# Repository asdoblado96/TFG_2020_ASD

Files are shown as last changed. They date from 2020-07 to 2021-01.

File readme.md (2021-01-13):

# Open source training FPGA board

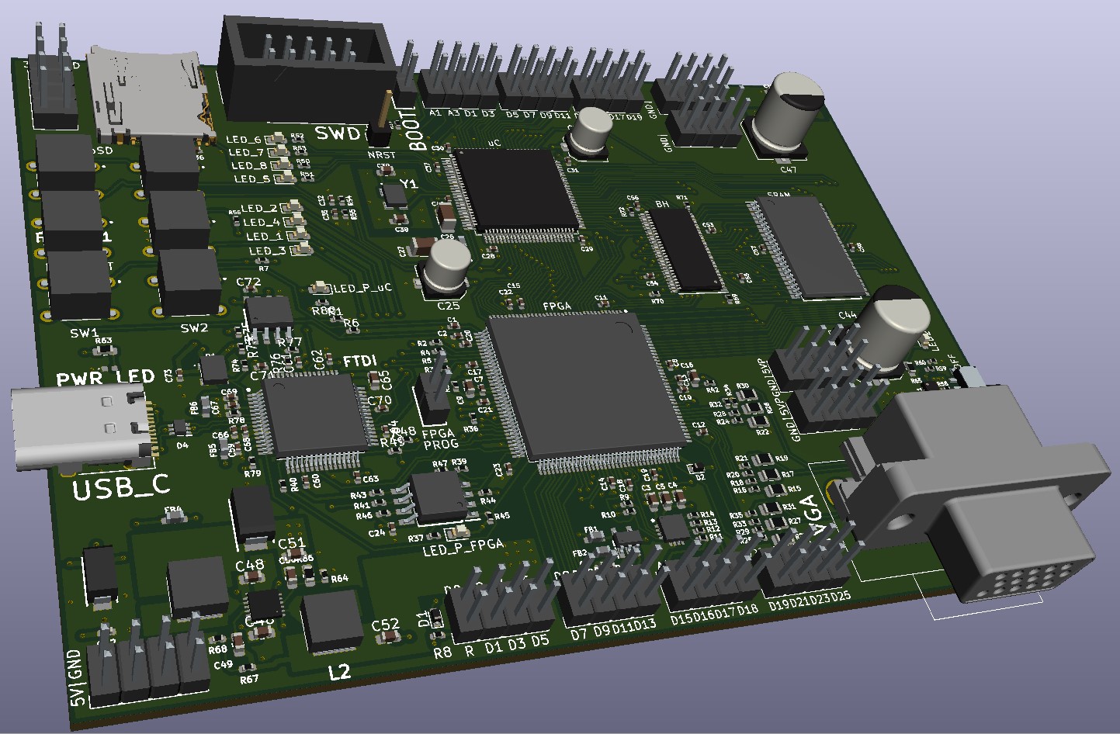
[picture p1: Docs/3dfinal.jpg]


This board was developed as a final bachelor project.

It came up as an opportunity to design an open source board that combines the advantages of both, microcontrollers and FPGAs, devices in one product. As an open source project, you will find all necessary files and information in this repository.

Please, take into account that the board was developped as an student. The purpose of this project was merely to learn about electronics and electronic product development. Please, don't hesitate to contact me in case of doubt, suggestion or if you find any error. 

Thank you.

## Features

* Open hardware
* FPGA:
    * iCE40HX4K (Lattice) FPGA development board (8K using opensource toolchain).
    * 32Mb flash memory for up to 30 bitstreams or FPGA user data.
    * 12 MHZ MEMS oscillator.
    * 4 general purpose LEDs (user LEDs).
    * 2 general purpose pushbuttons.
    * Reset pushbutton and accessible external pin.
    * VGA port.
    * 30 I/O pins (26 digital and 4 analog pins).
    * 4-Channels, 12 bits A/D converter.
    * Compatible with the opensource [Icestudio](https://github.com/FPGAwars/icestudio/).
    * Programmable by USB.
* Microcontroller:
    * STM32F091VC microcontroller.
    * 256Kbyte flash memory and 32Kbyte RAM memory.
    * Internal 8MHZ clock and external 32MHZ crystal oscillator clock.
    * 4 general purpose LEDs (user LEDs).
    * 2 general purpose pushbuttons.
    * Reset pushbutton and accessible external pin.
    * MicroSD card reader.
    * SWD connector for using ST-Link V2.
    * 24 I/O pins (20 digital and 4 analog pins).
    * 1 SPI, 1 I2C and 6 UART compatible pins.
    * Programmable by USB or by St-Link.
* General:
    * FTDI chip allows programming both devices (previously selected by an external jumper). 
    * 4MB shared SRAM between microcontroller and FPGA (to be used as storage or as a communication buffer between devices).
    * USB C power supply (up to 5A).
    * 24 accessible power pins (5V and 3.3V) and 24 GND pins.

## Author

* [Alejandro Sánchez Doblado](https://www.linkedin.com/in/alejandro-s%C3%A1nchez-doblado-014724183/)

## Credits

* This project was derived from the [Icezum Alhambra V2 board](https://github.com/FPGAwars/Alhambra-II-FPGA)

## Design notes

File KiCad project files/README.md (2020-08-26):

# TFG_2020_ASD
KiCad files of the project

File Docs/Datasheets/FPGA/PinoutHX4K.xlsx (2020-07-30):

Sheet: Pinout
iCE40 Pinout HX4K
Pin Function | Pin Type | Bank | (BG121) 121-Ball caBGA Ball Number | (CB132) 132-Ball csBGA Ball Number | (TQ144) 144-Pin TQFP Pin Number
IOL_2A | DPIO | 3 | B1 | B1 | 1 | D1
IOL_2B | DPIO | 3 | B2 | C1 | 2 | D0
IOL_3A | DPIO | 3 | - | - | 3 | D3
IOL_3B | DPIO | 3 | - | - | 4 | D2
GND | GND | GND | - | A9 | 5
VCCIO_3 | VCCIO | VCCIO | - | E3 | 6
IOL_4A | DPIO | 3 | C4 | C3 | 7 | D5
IOL_4B | DPIO | 3 | C3 | D3 | 8 | D4
IOL_5A | DPIO | 3 | C2 | D1 | 9 | D7
IOL_5B | DPIO | 3 | C1 | E1 | 10 | D6
IOL_8A | DPIO | 3 | E1 | D4 | 11
IOL_8B | DPIO | 3 | D1 | E4 | 12
IOL_9A | DPIO | 3 | D2 | F4 | -
IOL_9B | DPIO | 3 | D3 | F3 | -
GND | GND | GND | - | F1 | 13
GND | GND | GND | - | F7 | 14
IOL_10A | DPIO | 3 | E2 | H4 | 15
IOL_10B | DPIO | 3 | E3 | G4 | 16
IOL_12A | DPIO | 3 | F1 | J3 | 17
IOL_12B | DPIO | 3 | F2 | J1 | 18
IOL_13A | DPIO | 3 | F4 | G3 | 19 | D9
IOL_13B_GBIN7 | GBIN | 3 | F3 | G1 | 20 | D8
IOL_14A_GBIN6 | GBIN | 3 | G1 | H1 | 21 | D11
IOL_14B | DPIO | 3 | G2 | H3 | 22 | D10
IOL_17A | DPIO | 3 | G3 | - | 23
IOL_17B | DPIO | 3 | H3 | - | 24
IOL_18A | DPIO | 3 | H1 | K3 | 25
IOL_18B | DPIO | 3 | H2 | K4 | 26
VCC | VCC | VCC | - | F8 | 27
IOL_23A | DPIO | 3 | J1 | L1 | 28
IOL_23B | DPIO | 3 | K1 | M1 | 29
VCCIO_3 | VCCIO | VCCIO | E4 | J6 | 30
IOL_24A | DPIO | 3 | - | - | 31
IOL_24B | DPIO | 3 | - | - | 32
IOL_25A | DPIO | 3 | K2 | N1 | 33 | U_SW2
IOL_25B | DPIO | 3 | J2 | P1 | 34 | U_SW1
IOB_56 | PIO | 2 | L1 | P2 | 37
IOB_57 | PIO | 2 | J3 | - | 38
IOB_59 | PIO | 2 | - | P3 | -
IOB_61 | PIO | 2 | L2 | - | 39
VCC | VCC | VCC | D8 | G6 | 40
IOB_63 | PIO | 2 | K3 | M4 | 41
IOB_64 | PIO | 2 | J4 | M3 | 42 | LED3
IOB_71 | PIO | 2 | L3 | L5 | 43 | LED2
IOB_72 | PIO | 2 | L4 | L4 | 44 | LED1
IOB_73 | PIO | 2 | K4 | P4 | 45 | LED0
IOB_74 | PIO | 2 | - | P5 | -
IOB_77 | PIO | 2 | - | M6 | -
IOB_78 | PIO | 2 | J5 | L6 | -
VCCIO_2 | VCCIO | VCCIO | H6 | J9 | 46
IOB_79 | PIO | 2 | K5 | M7 | 47
IOB_80 | PIO | 2 | - | - | 48
IOB_81_GBIN5 | GBIN | 2 | L5 | P7 | 49 | ICE_CLK
IOB_82_GBIN4 | GBIN | 2 | K6 | P8 | 52
GNDPLL0 | GNDPLL | GNDPLL | L6 | L7 | 53
VCCPLL0 | VCCPLL | VCCPLL | J6 | M8 | 54
IOB_87 | PIO | 2 | H7 | L8 | -
IOB_89 | PIO | 2 | K7 | P9 | -
IOB_91 | PIO | 2 | J8 | M9 | 55
IOB_94 | PIO | 2 | L7 | - | 56
VCCIO_2 | VCCIO | VCCIO | - | M5 | 57
GND | GND | GND | E5 | G7 | 59
IOB_95 | PIO | 2 | - | - | 60
IOB_96 | PIO | 2 | - | - | 61
IOB_102 | PIO | 2 | - | - | 62
IOB_103_CBSEL0 | PIO | 2 | L8 | L9 | 63 | D12
IOB_104_CBSEL1 | PIO | 2 | H9 | P10 | 64 | D13
CDONE | CONFIG | 2 | K8 | M10 | 65
CRESET_B | CONFIG | 2 | L9 | L10 | 66
IOB_105_SDO | SPI | SPI | K9 | M11 | 67
IOB_106_SDI | SPI | SPI | J9 | P11 | 68
GND | GND | GND | E6 | G8 | 69
IOB_107_SCK | SPI | SPI | L10 | P12 | 70
IOB_108_SS | SPI | SPI | K10 | P13 | 71
VCC_SPI | SPI | SPI | L11 | L11 | 72
IOR_109 | PIO | 1 | - | M12 | 73
IOR_110 | PIO | 1 | - | P14 | 74
IOR_111 | PIO | 1 | - | L12 | 75
IOR_112 | PIO | 1 | - | N14 | 76
NC | NC | NC | - | M14 | 77
IOR_114 | PIO | 1 | J11 | L14 | 78
IOR_115 | PIO | 1 | K11 | K12 | 79
IOR_116 | PIO | 1 | H10 | K11 | 80
IOR_117 | PIO | 1 | J10 | K14 | 81
IOR_118 | PIO | 1 | G8 | J12 | 82
IOR_119 | PIO | 1 | H11 | J11 | 83 | ADC_SDA
IOR_120 | PIO | 1 | G10 | H12 | 84 | ADC_SCL
IOR_128 | PIO | 1 | G9 | H11 | 85
IOR_129 | PIO | 1 | G11 | G12 | -
GND | GND | GND | E7 | G9 | 86
IOR_136 | PIO | 1 | F10 | G11 | 87
IOR_137 | PIO | 1 | F9 | F12 | 88
VCCIO_1 | VCCIO | VCCIO | - | F9 | 89
IOR_138 | PIO | 1 | - | - | 90 | ADC_INT
IOR_139 | PIO | 1 | - | - | 91
VCC | VCC | VCC | D4 | H9 | 92
IOR_140_GBIN3 | GBIN | 1 | F11 | F14 | 93
IOR_141_GBIN2 | GBIN | 1 | E10 | G14 | 94
IOR_144 | PIO | 1 | E9 | F11 | 95
IOR_146 | PIO | 1 | E8 | E11 | 96
IOR_147 | PIO | 1 | D9 | E12 | 97
IOR_148 | PIO | 1 | E11 | E14 | 98
IOR_152 | PIO | 1 | D11 | D14 | 99
IOR_154 | PIO | 1 | D10 | C14 | -
VCCIO_1 | VCCIO | VCCIO | F8 | H14 | 100
IOR_160 | PIO | 1 | C11 | D12 | 101
IOR_161 | PIO | 1 | B11 | B14 | 102
GND | GND | GND | F5 | H6 | 103
IOR_164 | PIO | 1 | - | - | 104
IOR_165 | PIO | 1 | - | - | 105
IOR_166 | PIO | 1 | - | - | 106
IOR_167 | PIO | 1 | - | - | 107
VPP_2V5 | VPP | VPP | C10 | A14 | 108
VPP_FAST | VPP | VPP | B10 | A13 | 109
IOT_168 | PIO | 0 | A11 | - | 110
VCC | VCC | VCC | - | J4 | 111
IOT_169 | PIO | 0 | - | - | 112
IOT_170 | PIO | 0 | A10 | A12 | 113
IOT_171 | PIO | 0 | - | - | 114 | A0
IOT_172 | PIO | 0 | C9 | C12 | 115 | A1
IOT_173 | PIO | 0 | - | - | 116 | A2
IOT_174 | PIO | 0 | B9 | C11 | 117 | A3
IOT_177 | PIO | 0 | B8 | D10 | 118
IOT_178 | PIO | 0 | A9 | D11 | 119
IOT_179 | PIO | 0 | C8 | A11 | 120
IOT_181 | PIO | 0 | D7 | A10 | 121
IOT_186 | PIO | 0 | - | C10 | -
IOT_188 | PIO | 0 | - | D9 | -
IOT_190 | PIO | 0 | A8 | C9 | 122
VCCIO_0 | VCCIO | VCCIO | - | A8 | 123
IOT_191 | PIO | 0 | C7 | - | 124
IOT_192 | PIO | 0 | A7 | - | 125
VCCPLL1 | VCCPLL | VCCPLL | C6 | C8 | 126
GNDPLL1 | GNDPLL | GNDPLL | C5 | D8 | 127
IOT_197_GBIN1 | GBIN | 0 | B7 | A7 | 128
IOT_198_GBIN0 | GBIN | 0 | B6 | A6 | 129
IOT_200 | PIO | 0 | - | C7 | -
IOT_202 | PIO | 0 | - | D7 | -
IOT_206 | PIO | 0 | A6 | C6 | 130
IOT_207 | PIO | 0 | A5 | D6 | -
IOT_208 | PIO | 0 | B5 | A5 | -
IOT_211 | PIO | 0 | A4 | D5 | -
VCCIO_0 | VCCIO | VCCIO | - | F6 | 131
GND | GND | GND | F6 | H7 | 132
IOT_212 | PIO | 0 | D5 | C5 | 134
IOT_213 | PIO | 0 | - | - | 135
IOT_214 | PIO | 0 | - | - | 136
IOT_215 | PIO | 0 | - | - | 137
IOT_216 | PIO | 0 | - | - | 138
IOT_217 | PIO | 0 | - | - | 139
GND | GND | GND | F7 | H8 | 140
IOT_219 | PIO | 0 | B4 | A4 | 141
IOT_220 | PIO | 0 | - | - | 142
IOT_221 | PIO | 0 | B3 | C4 | 143
IOT_222 | PIO | 0 | A2 | A3 | 144
IOT_223 | PIO | 0 | A3 | A2 | -
IOT_225 | PIO | 0 | A1 | A1 | -
VCC | VCC | VCC | H8 | J7 | -
NC | NC | NC |  | - | 35
NC | NC | NC |  | - | 36
NC | NC | NC |  | - | 50
NC | NC | NC |  | - | 51
NC | NC | NC |  | - | 58
NC | NC | NC |  | - | 133
GND | GND | GND | G5 | J14 | -
GND | GND | GND | G6 | J8 | -
GND | GND | GND | G7 | L3 | -
GND | GND | GND | - | P6 | -
VCCIO_3 | VCCIO | VCCIO | G4 | K1 | -

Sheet: Revision History
Version | Date | Description
3.0 | 2017/05/5 | add "BG121" for "121-Ball caBGA"(new 9x9 mm package ucBGA121), Revision "iCE40HX08.pkt 1.1"
2.1 | 2013-06-13 | Included package ordering code.
2.0 | 2013-03-13 | Updated table format to include all packages
1.0 | 10/1/2012 | Chnaged name from "TQ144" to "144-pin TQFP" Production Release
0.92 | 2011-12-14 | Package drawing, removed option notes 6 and 7
0.91 | 2011-11-13 | 1K pins 40, 49, 50, 52, 133, 134 updated
0.9 | 2011-10-31 | Preliminary

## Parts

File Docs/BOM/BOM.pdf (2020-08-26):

Referencia | Valor | Huella | CantidadPrecio
> C1, C2, C7, C8, C10-C15, C17-C24, C28-C32, C35-C37, C40, C42, C53-C64, C66-C73 C100n | Capacitor_SMD:C_0402_1005Metric | 48 | 3.456
> C5, C9, C16, C34, C46, C48, C51, C52, C65 C10u | Capacitor_SMD:C_0603_1608Metric | 9 | 2.088
> C3, C4, C6, C41, C43, C45 | C100n | Capacitor_SMD:C_0603_1608Metric | 6 | 0.306
> C25, C33 | C4.7uElect | Capacitor_SMD:C_Elec_5x5.4 | 2 | 0.528
C26 | C1u | Capacitor_SMD:C_1206_3216Metric | 1 | 0.263
C27 | C10n | Capacitor_SMD:C_1206_3216Metric | 1 | 0.082
> C38, C39 | C20p | Capacitor_SMD:C_0603_1608Metric | 2 | 0.229
> C44, C47 | C220uElect | Capacitor_SMD:CP_Elec_8x10 | 2 | 0.638
> C49, C50 | 100p | Capacitor_SMD:C_0603_1608Metric | 2 | 0.148
> D1, D2 | D_Schottky | Diode_SMD:D_SOD-523 | 2 | 0.078
D3 | 824500500 | TFG_20:DIOM5127X250N | 1 | 0.225
D4 | 82400152 | TFG_20:SOTFL50P160X60-6N | 1 | 0.48
> FB1-FB6 | BLM18KG331SN1D | TFG_20:BEADC1608X95N | 6 | 0.228
IC1 | ADS7924IRTER | TFG_20:QFN50P300X300X80-17N-D | 1 | 1.6
IC2 | NCP114BSN330T1G | TFG_20:SOT95P275X110-5N | 1 | 0.2
IC3 | iCE40HX4K-TQ144 | TFG_20:QFP50P2200X2200X160-144N | 1 | 5.34
IC4 | W25Q32JVSSIQ | TFG_20:SOIC127P790X216-8N | 1 | 0.584
IC5 | NCP708MU330TAG | TFG_20:SON95P300X300X55-7N | 1 | 0.39
IC6 | IS61WV25616EDBLL-10TLI | TFG_20:SOP80P1176X120-44N | 1 | 2.33
IC7 | 93LC56C-I_SN | TFG_20:SOIC127P600X175-8N | 1 | 0.203
> J1-J4, J6, J7, J9, J13-J20 | 10129381-908002BLF | HDRV8W67P254_2X4_1016X483X858P | 7 | 4.2
J5 | L77HDE15SD1CH4RHNVGA | TFG_20:L77HDE15SD1CH4RHNVGA | 1 | 1.38
J8 | 1761681-3 | SHDR10W67P254_2X5_2032X916X922P | 1 | 1.26
J10 | Conn_01x01 | Connector_PinHeader_2.54mm:PinHeader_1x01_P2.54mm_Vertical 1 | 0.085
J11 | Micro_SD_Card | Connector_Card:microSD_HC_Molex_104031-08111 | 2.92
J12 | USB_C_Receptacle_USB2.0 | Connector_USB:USB_C_Receptacle_Amphenol_12401610E4-2A 1 | 1.6
> L1, L2 | LQH5BPN4R7NT0L | TFG_20:LQH5BPB100MT0L | 2 | 0.42
> LED1, LED_1, LED_8, LED_FP1 | LED_AMARILLO | LED_SMD:LED_0603_1608Metric | 4 | 0.4
> LED2, LED_2, LED_7, PWR_LED1 LED_AZUL | LED_SMD:LED_0603_1608Metric | 4 | 0.474
> LED_3, LED_6 | LED_VERDE | LED_SMD:LED_0603_1608Metric | 2 | 0.332
> LED_4, LED_5 | LED_ROJO | LED_SMD:LED_0603_1608Metric | 2 | 0.292
O1 | DSC1001CL2 | TFG_20:DSC1001CI50081920 | 1 | 0.805

Q1 | DMP1005UFDF-7 | TFG_20:DFN-6-2EP-2.05-2.05 | 1 | 0.362
> R1, R6, R8-R10, R36, R44-R48, R54, R55, R57, R59, R60, R66-R73, R75, R76, R78 R10k | Resistor_SMD:R_0402_1005Metric | 27 | 1.215
> R2-R5, R39-R41, R43, R50-R53 | R470 | Resistor_SMD:R_0402_1005Metric | 12 | 0.4548
> R7, R49, R56, R61, R62, R79 | R1K | Resistor_SMD:R_0402_1005Metric | 6 | 0.176
> R11-R14, R21, R34, R35, R38, R42, R58, R74, R80 R100 | Resistor_SMD:R_0402_1005Metric | 12 | 1.68
> R15, R17, R19, R22, R23, R26, R27, R30, R31 R309 | Resistor_SMD:R_0805_2012Metric | 9 | 0.9
> R16, R18, R20, R24, R25, R28, R29, R32, R33 R619 | Resistor_SMD:R_0402_1005Metric | 9 | 0.216
> R37,R63, R65, R77 | R2k2 | Resistor_SMD:R_0402_1005Metric | 4 | 0.04
R64 | 45k | Resistor_SMD:R_0603_1608Metric | 1 | 0.79
S1 | PCM12SMTR | TFG_20:PCM12SMTR_1 | 1 | 0.8
U1 | STM32F091VCTx | Package_QFP:LQFP-100_14x14mm_P0.5mm | 1 | 4.26
U2 | PAM2306AYPKB | Package_DFN_QFN:WDFN-12-1EP_3x3mm_P0.45mm_EP1.7x2.5mm 1 | 0.344
U3 | SN74ALVCH162827 | Package_SO:TSSOP-56_6.1x14mm_P0.5mm | 1 | 1.56
U4 | FT2232H | TFG_20:QFP50P1200X1200X160-64N | 1 | 4.19
> FPGA_R1, uC_R1, USW1-USW4 | FSM2JLH | FSM2JLH | 6 | 0.6
Y1 | ECS-320-12-33B-7KM-TR | ECS3201233B7KMTR | 1 | 0.33
Z1 | 3.3V | TFG_20:DIOM5436X247N | 1 | 0.12
| | | | 51.602

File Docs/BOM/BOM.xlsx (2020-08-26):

Referencia | Valor | Huella | Datasheet | Cantidad | Precio
> C1, C2, C7, C8, C10-C15, C17-C24, C28-C32, C35-C37, C40, C42, C53-C64, C66-C73 | C100n | Capacitor_SMD:C_0402_1005Metric | https://es.rs-online.com/web/p/mlccs-condensadores-ceramicos-multicapa/9155613/ | 48 | 3.456
> C5, C9, C16, C34, C46, C48, C51, C52, C65 | C10u | Capacitor_SMD:C_0603_1608Metric | https://es.rs-online.com/web/p/mlccs-condensadores-ceramicos-multicapa/7882893/ | 9 | 2.088
> C3, C4, C6, C41, C43, C45 | C100n | Capacitor_SMD:C_0603_1608Metric | https://es.rs-online.com/web/p/mlccs-condensadores-ceramicos-multicapa/2644630/ | 6 | 0.306
> C25, C33 | C4.7uElect | Capacitor_SMD:C_Elec_5x5.4 | https://es.rs-online.com/web/p/condensadores-de-aluminio/5369916/ | 2 | 0.528
C26 | C1u | Capacitor_SMD:C_1206_3216Metric | https://es.rs-online.com/web/p/mlccs-condensadores-ceramicos-multicapa/6911195/ | 1 | 0.263
C27 | C10n | Capacitor_SMD:C_1206_3216Metric | https://es.rs-online.com/web/p/mlccs-condensadores-ceramicos-multicapa/2644141/ | 1 | 0.082
> C38, C39 | C20p | Capacitor_SMD:C_0603_1608Metric | https://es.rs-online.com/web/p/mlccs-condensadores-ceramicos-multicapa/7880355/ | 2 | 0.229
> C44, C47 | C220uElect | Capacitor_SMD:CP_Elec_8x10 | https://es.rs-online.com/web/p/condensadores-de-aluminio/7568092/ | 2 | 0.638
> C49, C50 | 100p | Capacitor_SMD:C_0603_1608Metric | https://es.rs-online.com/web/p/mlccs-condensadores-ceramicos-multicapa/2644523/ | 2 | 0.148
> D1, D2 | D_Schottky | Diode_SMD:D_SOD-523 | https://es.rs-online.com/web/p/diodos-schottky-y-rectificadores/7916321/ | 2 | 0.078
D3 | 824500500 | TFG_20:DIOM5127X250N | https://componentsearchengine.com/Datasheets/1/824500500.pdf | 1 | 0.225
D4 | 82400152 | TFG_20:SOTFL50P160X60-6N | http://uk.rs-online.com/web/p/products/7546203P | 1 | 0.48
> FB1-FB6 | BLM18KG331SN1D | TFG_20:BEADC1608X95N | http://uk.rs-online.com/web/p/products/7926265P | 6 | 0.228
IC1 | ADS7924IRTER | TFG_20:QFN50P300X300X80-17N-D | http://www.ti.com/lit/gpn/ads7924 | 1 | 1.6
IC2 | NCP114BSN330T1G | TFG_20:SOT95P275X110-5N | http://uk.rs-online.com/web/p/products/1263179P | 1 | 0.2
IC3 | iCE40HX4K-TQ144 | TFG_20:QFP50P2200X2200X160-144N | https://componentsearchengine.com/Datasheets/1/iCE40HX4K-TQ144.pdf | 1 | 5.34
IC4 | W25Q32JVSSIQ | TFG_20:SOIC127P790X216-8N | https://www.winbond.com/resource-files/w25q32jv%20spi%20revc%2008302016.pdf | 1 | 0.584
IC5 | NCP708MU330TAG | TFG_20:SON95P300X300X55-7N | https://componentsearchengine.com/Datasheets/1/NCP708MU330TAG.pdf | 1 | 0.39
IC6 | IS61WV25616EDBLL-10TLI | TFG_20:SOP80P1176X120-44N | https://componentsearchengine.com/Datasheets/1/IS61WV25616EDBLL-10TLI.pdf | 1 | 2.33
IC7 | 93LC56C-I_SN | TFG_20:SOIC127P600X175-8N | https://componentsearchengine.com/Datasheets/1/93LC56C-I_SN.pdf | 1 | 0.203
> J1-J4, J6, J7, J9, J13-J20 | 10129381-908002BLF | HDRV8W67P254_2X4_1016X483X858P | https://cdn.amphenol-icc.com/media/wysiwyg/files/drawing/10129381.pdf | 7 | 4.2
J5 | L77HDE15SD1CH4RHNVGA | TFG_20:L77HDE15SD1CH4RHNVGA | https://componentsearchengine.com/Datasheets/1/L77HDE15SD1CH4RHNVGA.pdf | 1 | 1.38
J8 | 1761681-3 | SHDR10W67P254_2X5_2032X916X922P | http://www.te.com/commerce/DocumentDelivery/DDEController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 | 1 | 1.26
J10 | Conn_01x01 | Connector_PinHeader_2.54mm:PinHeader_1x01_P2.54mm_Vertical | ~ | 1 | 0.085
J11 | Micro_SD_Card | Connector_Card:microSD_HC_Molex_104031-0811 | http://katalog.we-online.de/em/datasheet/693072010801.pdf | 1 | 2.92
J12 | USB_C_Receptacle_USB2.0 | Connector_USB:USB_C_Receptacle_Amphenol_12401610E4-2A | https://www.usb.org/sites/default/files/documents/usb_type-c.zip | 1 | 1.6
> L1, L2 | LQH5BPN4R7NT0L | TFG_20:LQH5BPB100MT0L | http://uk.rs-online.com/web/p/products/8712085P | 2 | 0.42
> LED1, LED_1, LED_8, LED_FP1 | LED_AMARILLO | LED_SMD:LED_0603_1608Metric | https://es.rs-online.com/web/p/leds/6546079/ | 4 | 0.4
> LED2, LED_2, LED_7, PWR_LED1 | LED_AZUL | LED_SMD:LED_0603_1608Metric | https://es.rs-online.com/web/p/leds/6973610/ | 4 | 0.474
> LED_3, LED_6 | LED_VERDE | LED_SMD:LED_0603_1608Metric | https://es.rs-online.com/web/p/leds/6973715/ | 2 | 0.332
> LED_4, LED_5 | LED_ROJO | LED_SMD:LED_0603_1608Metric | https://es.rs-online.com/web/p/leds/7166570/ | 2 | 0.292
O1 | DSC1001CL2 | TFG_20:DSC1001CI50081920 | https://www.mouser.es/datasheet/2/268/20005529A-1149183.pdf | 1 | 0.805
Q1 | DMP1005UFDF-7 | TFG_20:DFN-6-2EP-2.05-2.05 | https://es.rs-online.com/web/p/mosfet/1827235/ | 1 | 0.362
> R1, R6, R8-R10, R36, R44-R48, R54, R55, R57, R59, R60, R66-R73, R75, R76, R78 | R10k | Resistor_SMD:R_0402_1005Metric | https://es.rs-online.com/web/p/resistencias-fijas-para-montaje-en-superficie/6784697/ | 27 | 1.215
> R2-R5, R39-R41, R43, R50-R53 | R470 | Resistor_SMD:R_0402_1005Metric | https://es.rs-online.com/web/p/resistencias-fijas-para-montaje-en-superficie/1991341/ | 12 | 0.4548
> R7, R49, R56, R61, R62, R79 | R1K | Resistor_SMD:R_0402_1005Metric | https://es.rs-online.com/web/p/resistencias-fijas-para-montaje-en-superficie/7014924/ | 6 | 0.176
> R11-R14, R21, R34, R35, R38, R42, R58, R74, R80 | R100 | Resistor_SMD:R_0402_1005Metric | https://es.rs-online.com/web/p/resistencias-fijas-para-montaje-en-superficie/8121739/ | 12 | 1.68
> R15, R17, R19, R22, R23, R26, R27, R30, R31 | R309 | Resistor_SMD:R_0805_2012Metric | https://es.rs-online.com/web/p/resistencias-fijas-para-montaje-en-superficie/7085979/ | 9 | 0.9
> R16, R18, R20, R24, R25, R28, R29, R32, R33 | R619 | Resistor_SMD:R_0402_1005Metric | https://es.rs-online.com/web/p/resistencias-fijas-para-montaje-en-superficie/1226449/ | 9 | 0.216
> R37,R63, R65, R77 | R2k2 | Resistor_SMD:R_0402_1005Metric | https://es.rs-online.com/web/p/resistencias-fijas-para-montaje-en-superficie/6789071/ | 4 | 0.04
R64 | 45k | Resistor_SMD:R_0603_1608Metric | https://es.rs-online.com/web/p/resistencias-fijas-para-montaje-en-superficie/8409275/ | 1 | 0.79
S1 | PCM12SMTR | TFG_20:PCM12SMTR_1 | http://uk.rs-online.com/web/p/products/7931721P | 1 | 0.8
U1 | STM32F091VCTx | Package_QFP:LQFP-100_14x14mm_P0.5mm | http://www.st.com/st-web-ui/static/active/en/resource/technical/document/datasheet/DM00115237.pdf | 1 | 4.26
U2 | PAM2306AYPKB | Package_DFN_QFN:WDFN-12-1EP_3x3mm_P0.45mm_EP1.7x2.5mm | https://www.diodes.com/assets/Datasheets/PAM2306.pdf | 1 | 0.344
U3 | SN74ALVCH162827 | Package_SO:TSSOP-56_6.1x14mm_P0.5mm | https://www.mouser.es/ProductDetail/Texas-Instruments/SN74ALVCH162836GR | 1 | 1.56
U4 | FT2232H | TFG_20:QFP50P1200X1200X160-64N | https://www.ftdichip.com/Support/Documents/DataSheets/ICs/DS_FT2232H.pdf | 1 | 4.19
> FPGA_R1, uC_R1, USW1-USW4 | FSM2JLH | FSM2JLH | https://www.te.com/commerce/DocumentDelivery/DDEController?Action=showdoc | 6 | 0.6
Y1 | ECS-320-12-33B-7KM-TR | ECS3201233B7KMTR | https://componentsearchengine.com/Datasheets/1/ECS-320-12-33B-7KM-TR.pdf | 1 | 0.33
Z1 | 3.3V | TFG_20:DIOM5436X247N | http://uk.rs-online.com/web/p/products/5453308P | 1 | 0.12
 |  |  |  |  | 51.6018

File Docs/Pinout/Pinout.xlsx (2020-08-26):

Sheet: uC
Pin | UART | SPI | I2C | Otro
A0 | UART1_TX |  |  | EVENT
A1 | UART1_RX |  |  | EVENT
A2 | UART2_TX | SPI_MISO |  | EVENT
A3 | UART2_RX | SPI_MOSI |  | EVENT
D0 |  |  |  | EVENT
 |  |  |  | TIM1_CH1
D1 |  |  |  | EVENT
 |  |  |  | TIM2_CH1
D2 |  | SPI_SS | I2C_SDA | EVENT
 |  |  |  | TIM2_CH1
D3 |  |  | I2C_SCL | TIM1_CH1
D4 | UART3_RX |  | I2C_SDA | TIM2_CH1N
D5 | UART3_TX |  | I2C_SCL | TIM1_CH1N
D6 |  |  |  | WAKEUP1
 |  |  |  | TIM3_CH2
D7 | UART4_RX |  |  | TIM3_CH1
D8 | UART4_TX |  |  | TIM2_CH2
D9 | USART_CK
D10 | USART_RX
D11 | USART_TX
D12 | USART_RTS | SPI_MOSI
D13 | USART_CTS | SPI_MISO
D14 | UART4_RX
D15 |  | SPI_SCK
D16 |  | SPI_SS
D17 | UART4_TX
D18 | UART5_RX
D19 | UART5_TX

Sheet: FPGA
PIN | Función
D19 | GBIN3
D20 | GBIN2

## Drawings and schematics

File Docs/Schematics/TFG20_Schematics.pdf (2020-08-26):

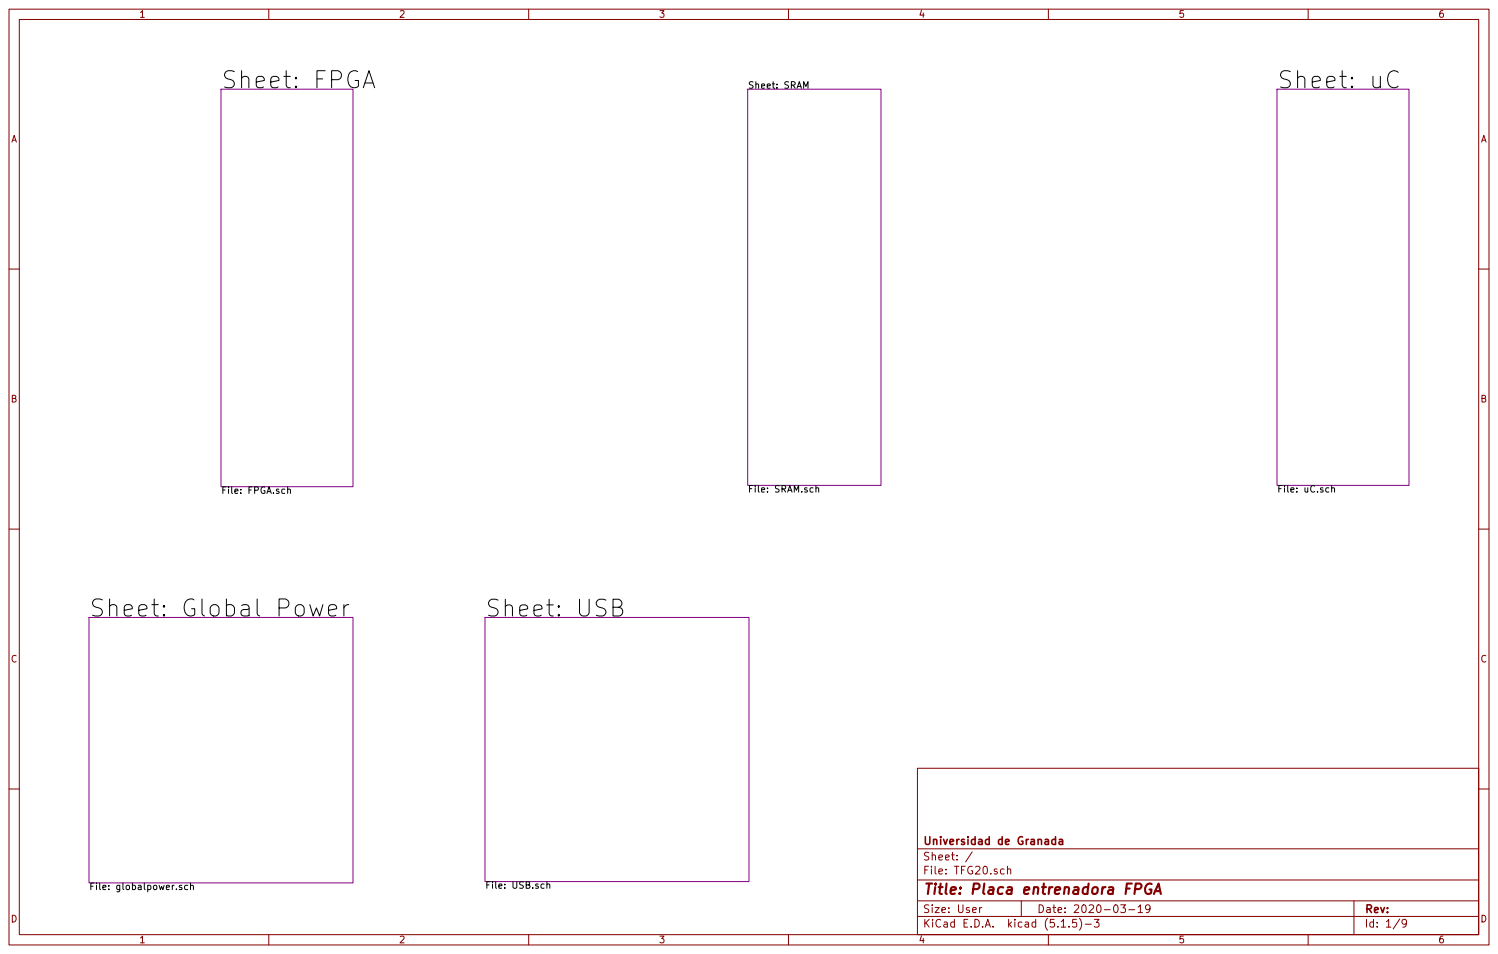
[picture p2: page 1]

Id: 1/9 Title: Placa entrenadora FPGA File: TFG20.sch Sheet: / Universidad de Granada Sheet: FPGA

File: uC.sch Sheet: Global Power

File: SRAM.sch Sheet: USB

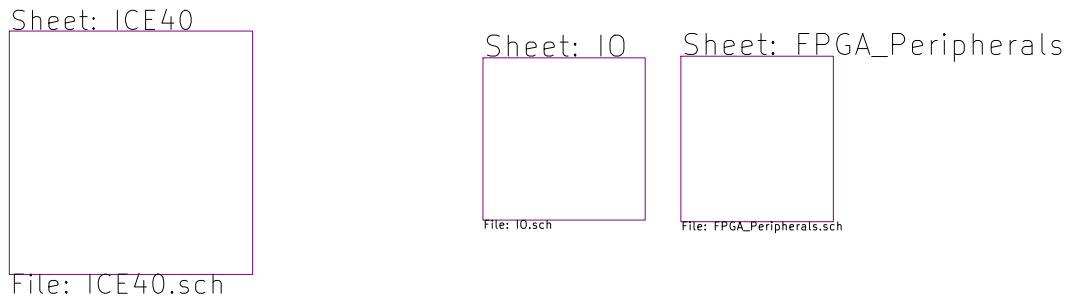
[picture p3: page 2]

Id: 2/9 Title: File: FPGA.sch Sheet: /FPGA/ Sheet: IO

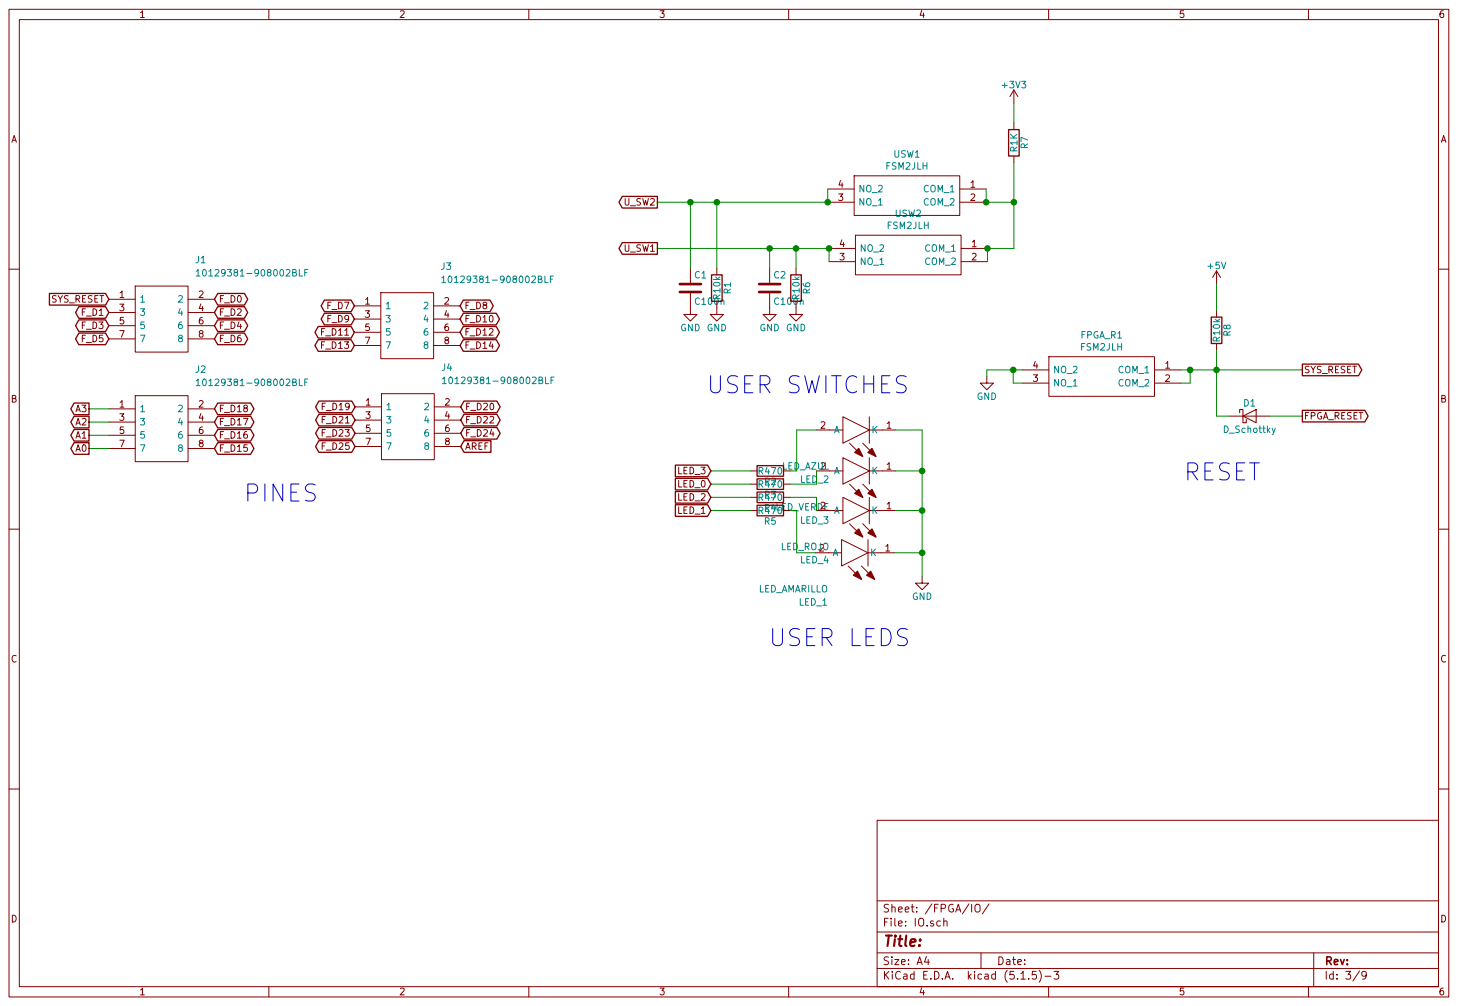
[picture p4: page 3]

Id: 3/9 Title: File: IO.sch Sheet: /FPGA/IO/

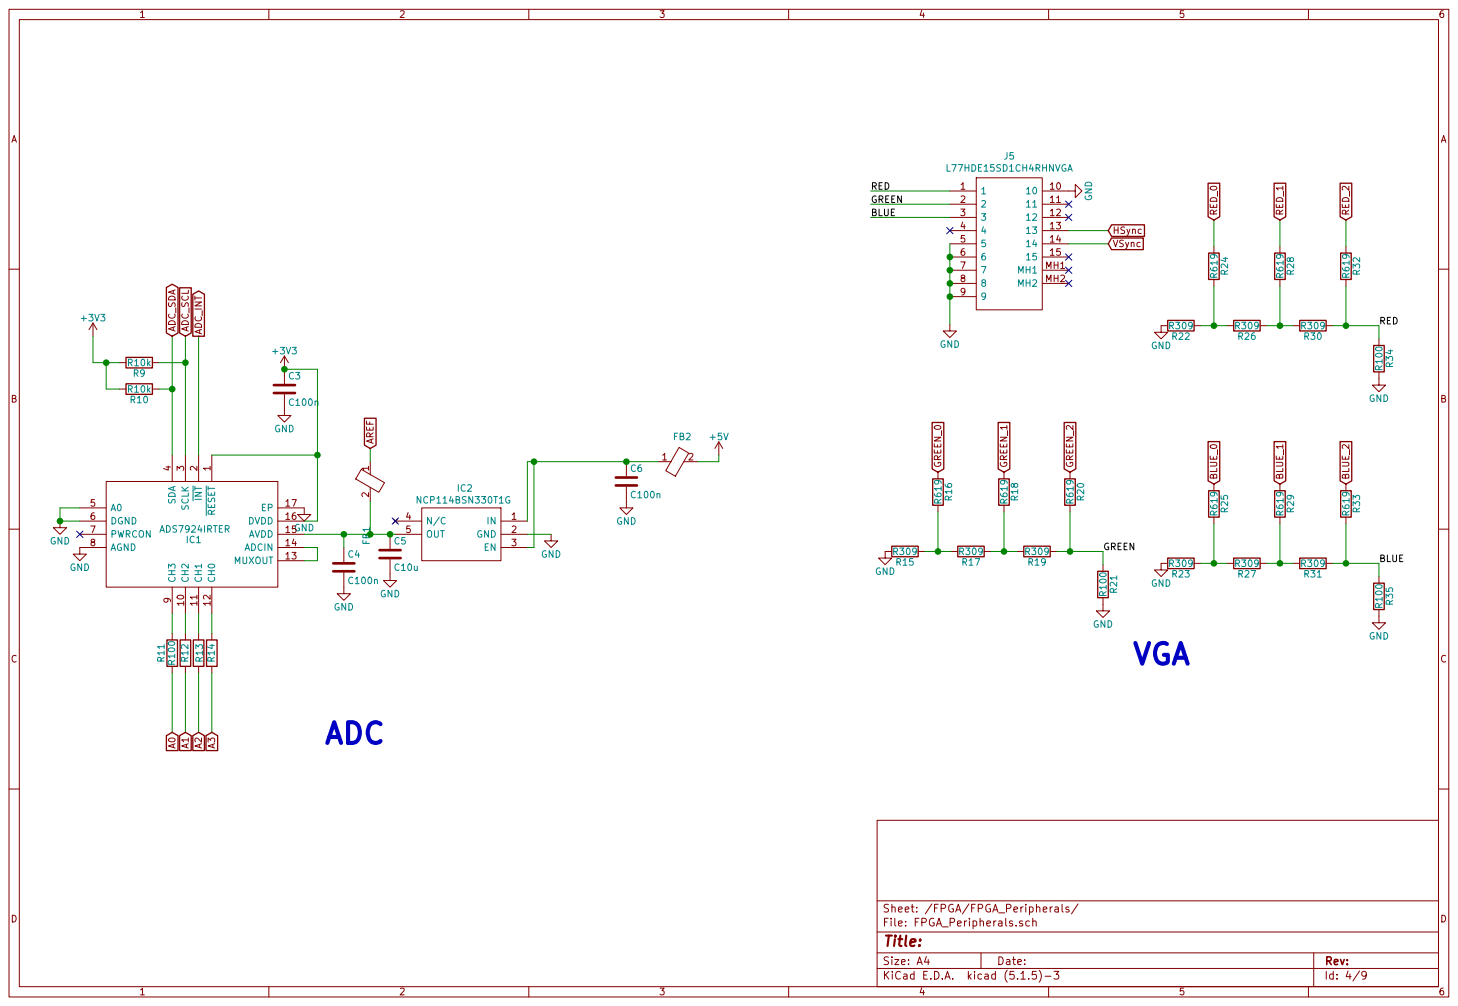
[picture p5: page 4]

1 CH2 10 CH1 11 CH0 12 MUXOUT 13 ADCIN 14 AVDD 15 DVDD 16 EP 17 INT

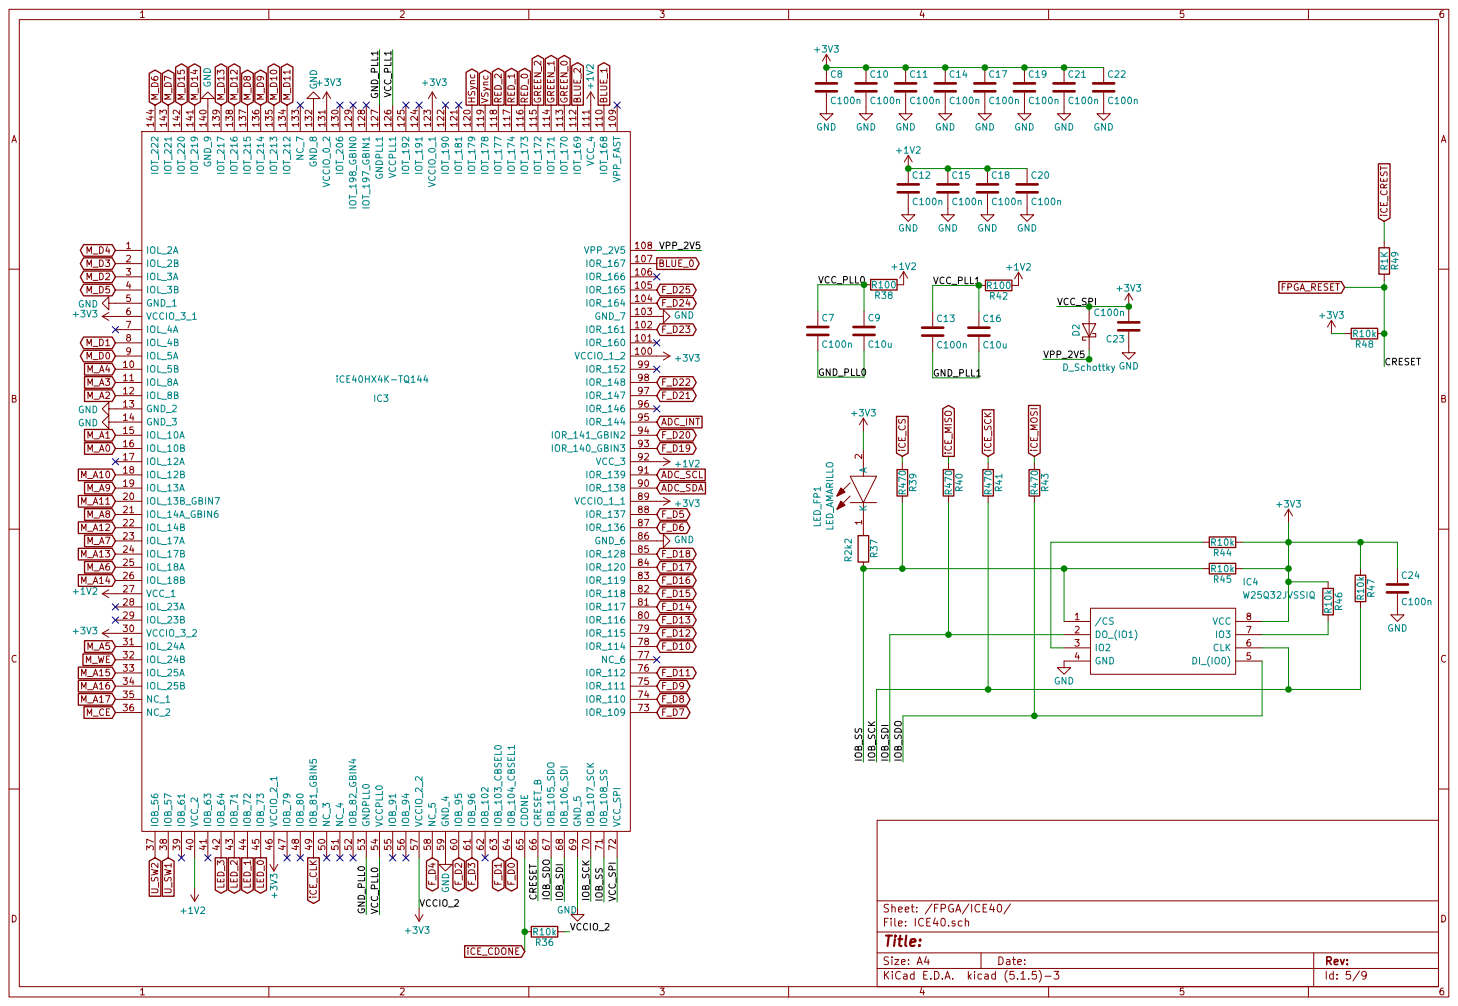
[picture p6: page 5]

Id: 5/9 Title: File: ICE40.sch Sheet: /FPGA/ICE40/ R470 R40 +1V2

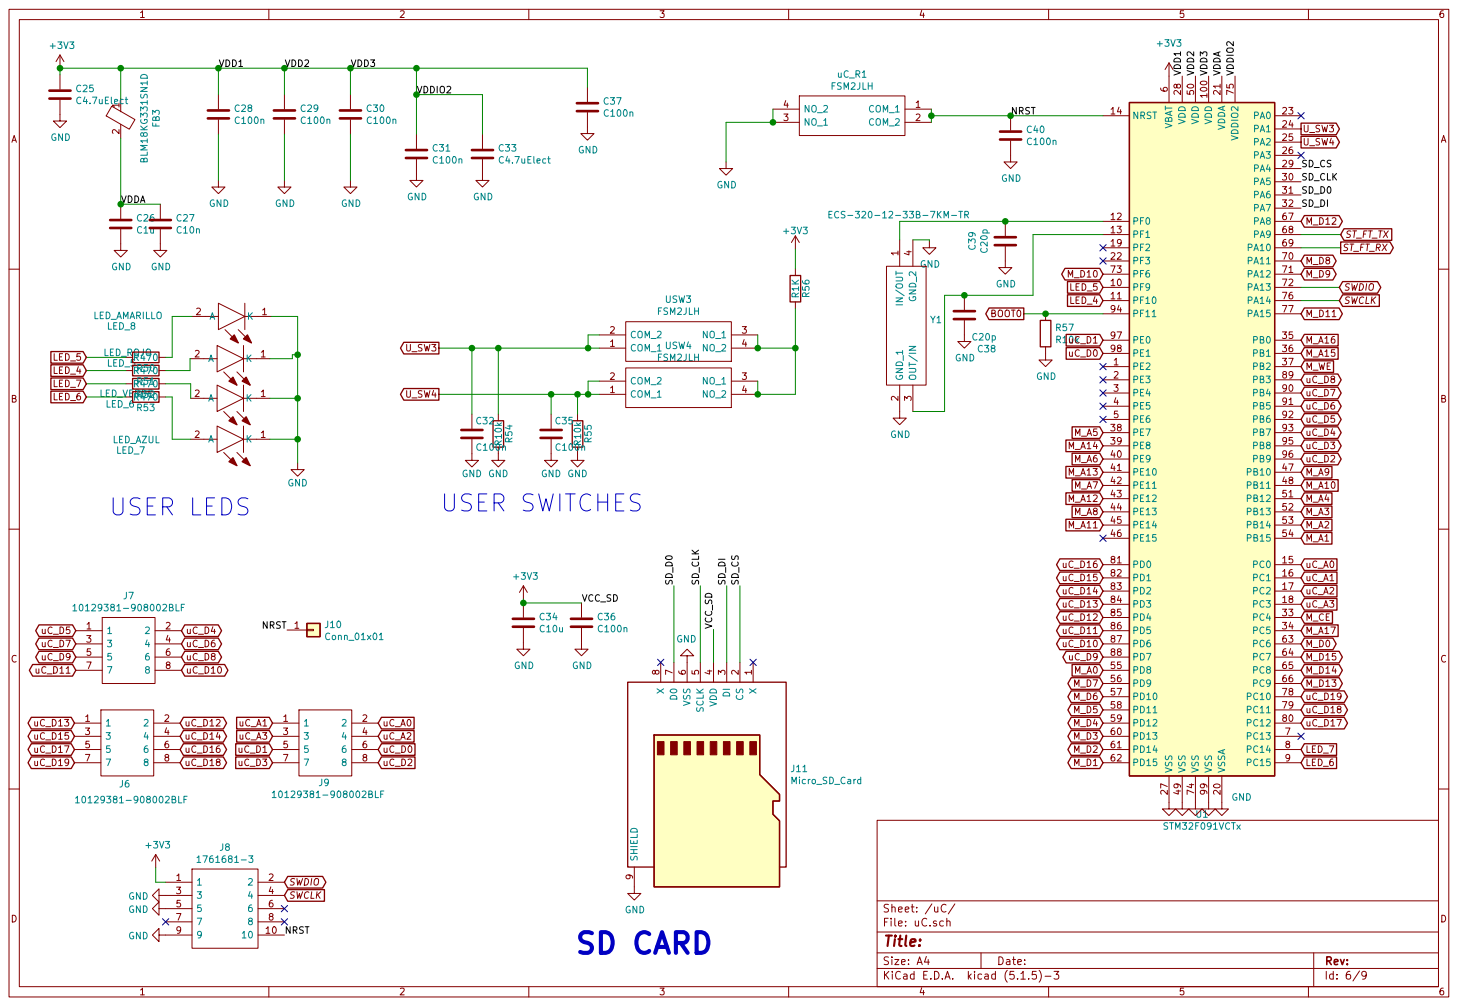
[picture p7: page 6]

Id: 6/9 Title: File: uC.sch Sheet: /uC/

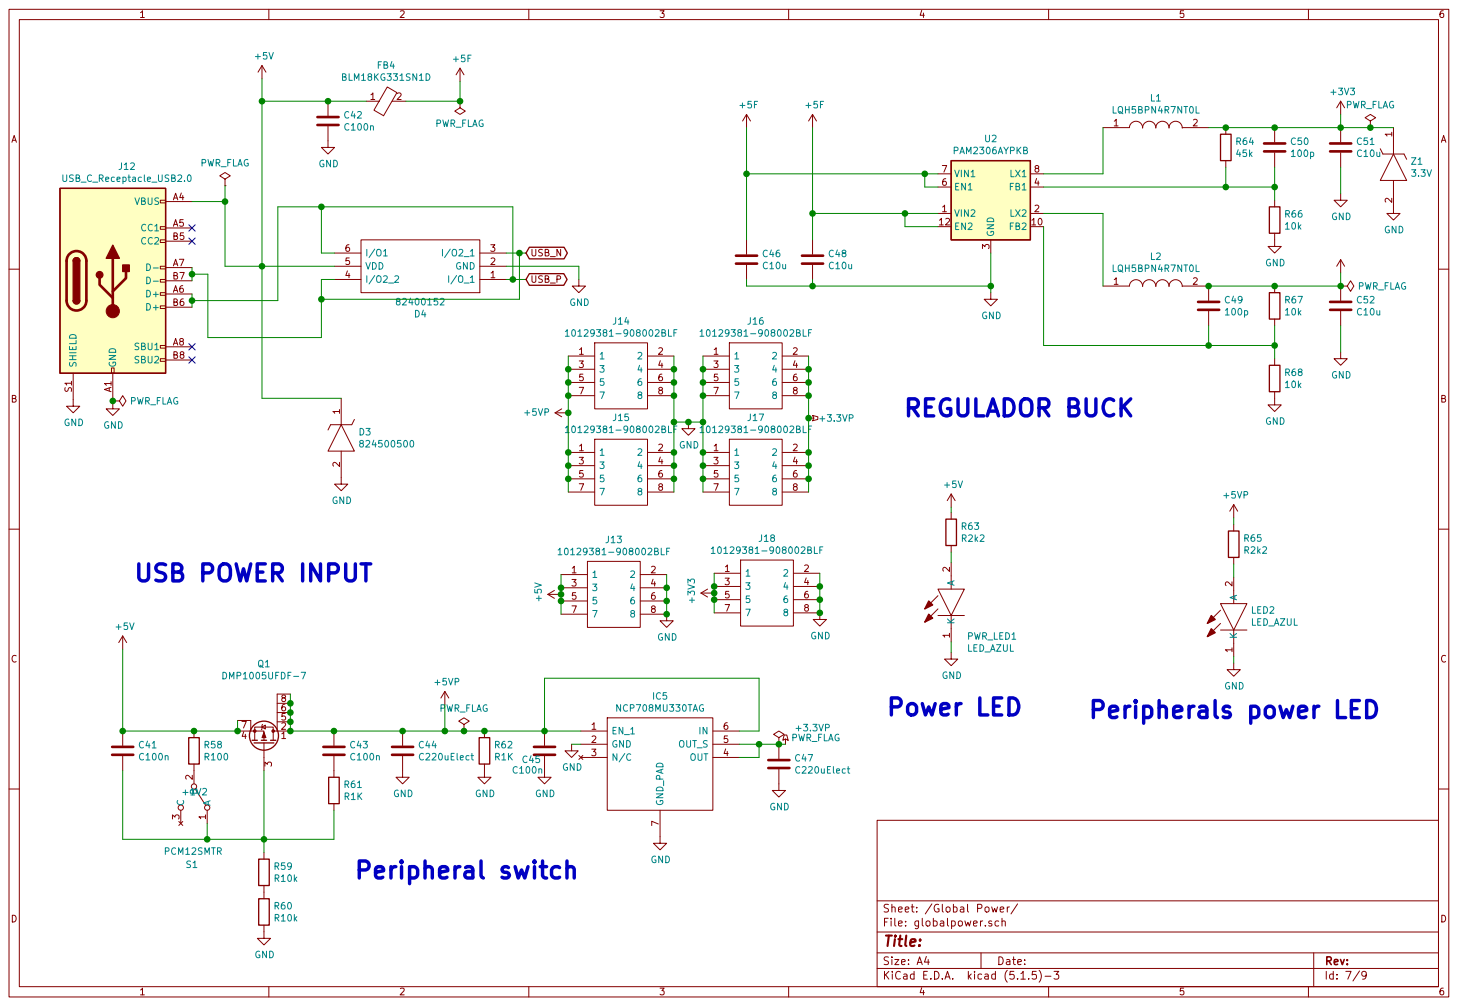
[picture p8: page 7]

File: globalpower.sch Sheet: /Global Power/ C41 C100n

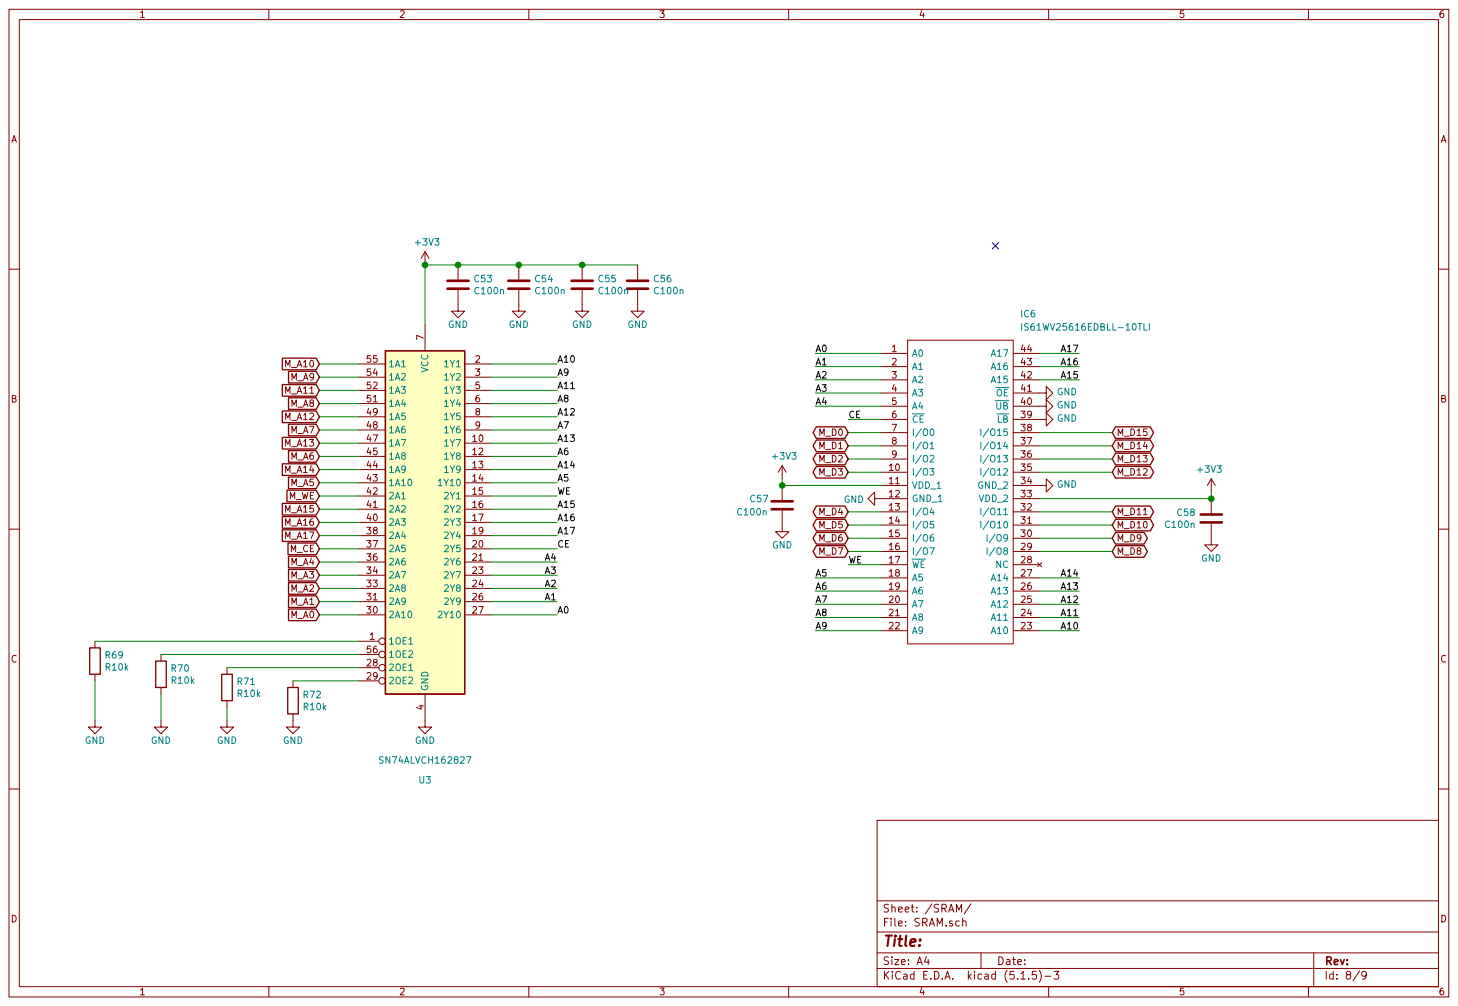
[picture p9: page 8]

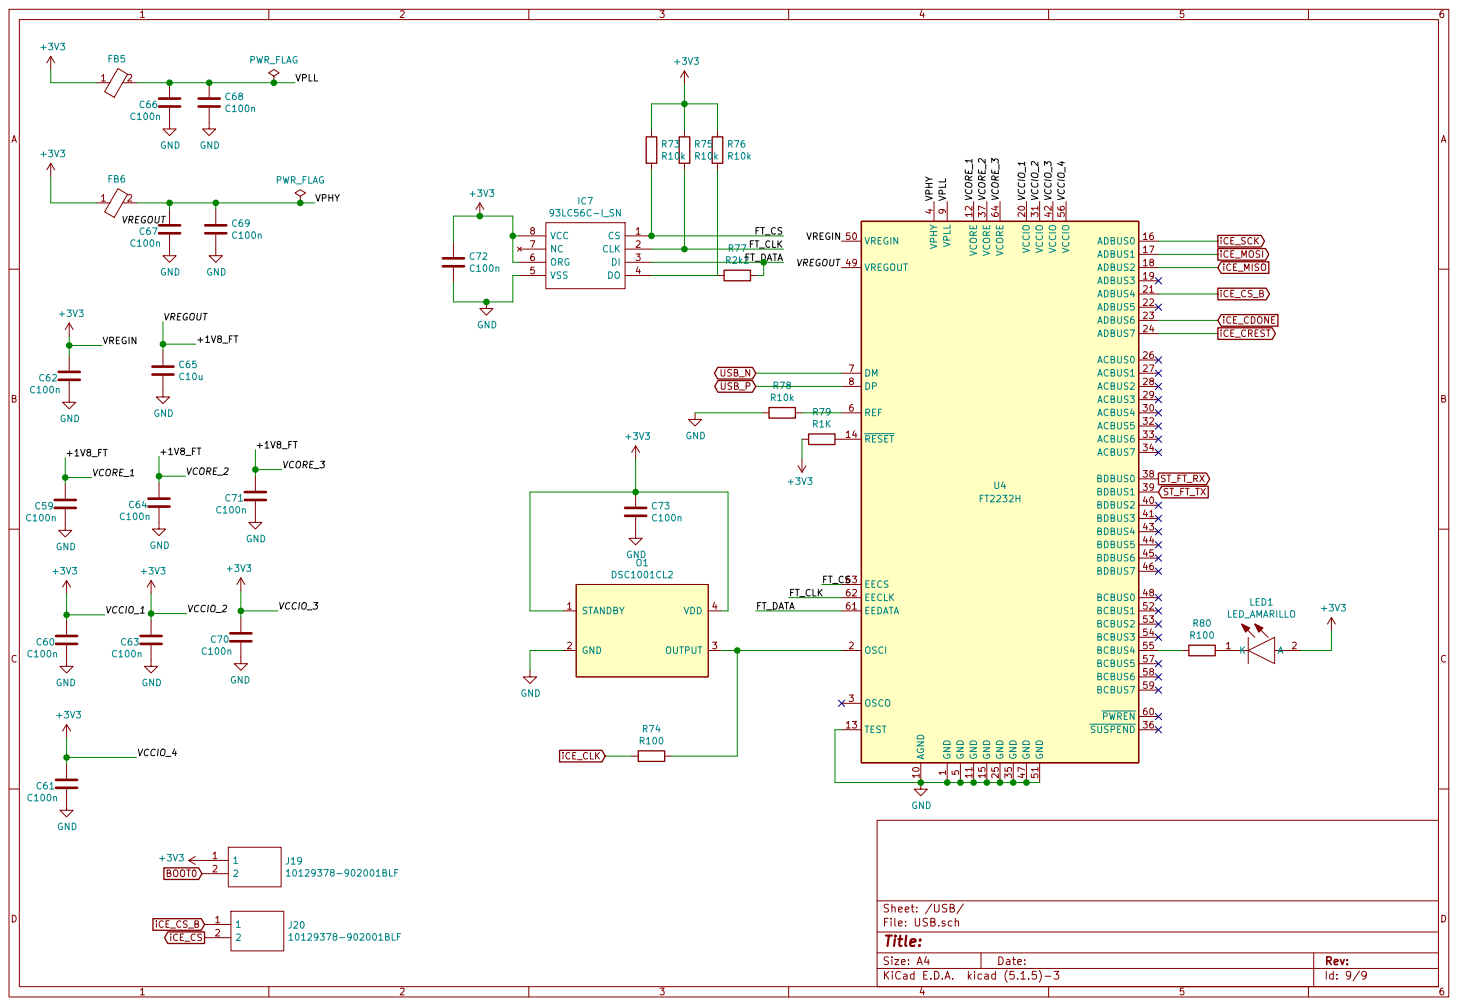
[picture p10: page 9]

1 AGND 10 GND 11 VCORE 12 TEST 13 RESET 14 GND 15 ADBUS0 16 ADBUS1 17 ADBUS2 18 ADBUS3 19 OSCI 2 VCCIO 20 ADBUS4 21 ADBUS5 22 ADBUS6 23 ADBUS7 24 GND 25 ACBUS0 26 ACBUS1 27 ACBUS2 28 ACBUS3 29 OSCO 3 ACBUS4 30 VCCIO 31 ACBUS5 32 ACBUS6 33 ACBUS7 34 GND 35 SUSPEND 36 VCORE 37 BDBUS0 38 BDBUS1 39 VPHY

4 BDBUS2 40 BDBUS3 41 VCCIO 42 BDBUS4 43 BDBUS5 44 BDBUS6 45 BDBUS7 46 GND 47 BCBUS0 48 VREGOUT 49 GND

5 VREGIN 50 GND 51 BCBUS1 52 BCBUS2 53 BCBUS3 54 BCBUS4 55 VCCIO 56 BCBUS5 57 BCBUS6 58 BCBUS7 59 REF 6 PWREN 60 EEDATA 61 EECLK 62 EECS 63 VCORE 64 DM 7 DP 8 VPLL

Id: 9/9 Title: File: USB.sch Sheet: /USB/

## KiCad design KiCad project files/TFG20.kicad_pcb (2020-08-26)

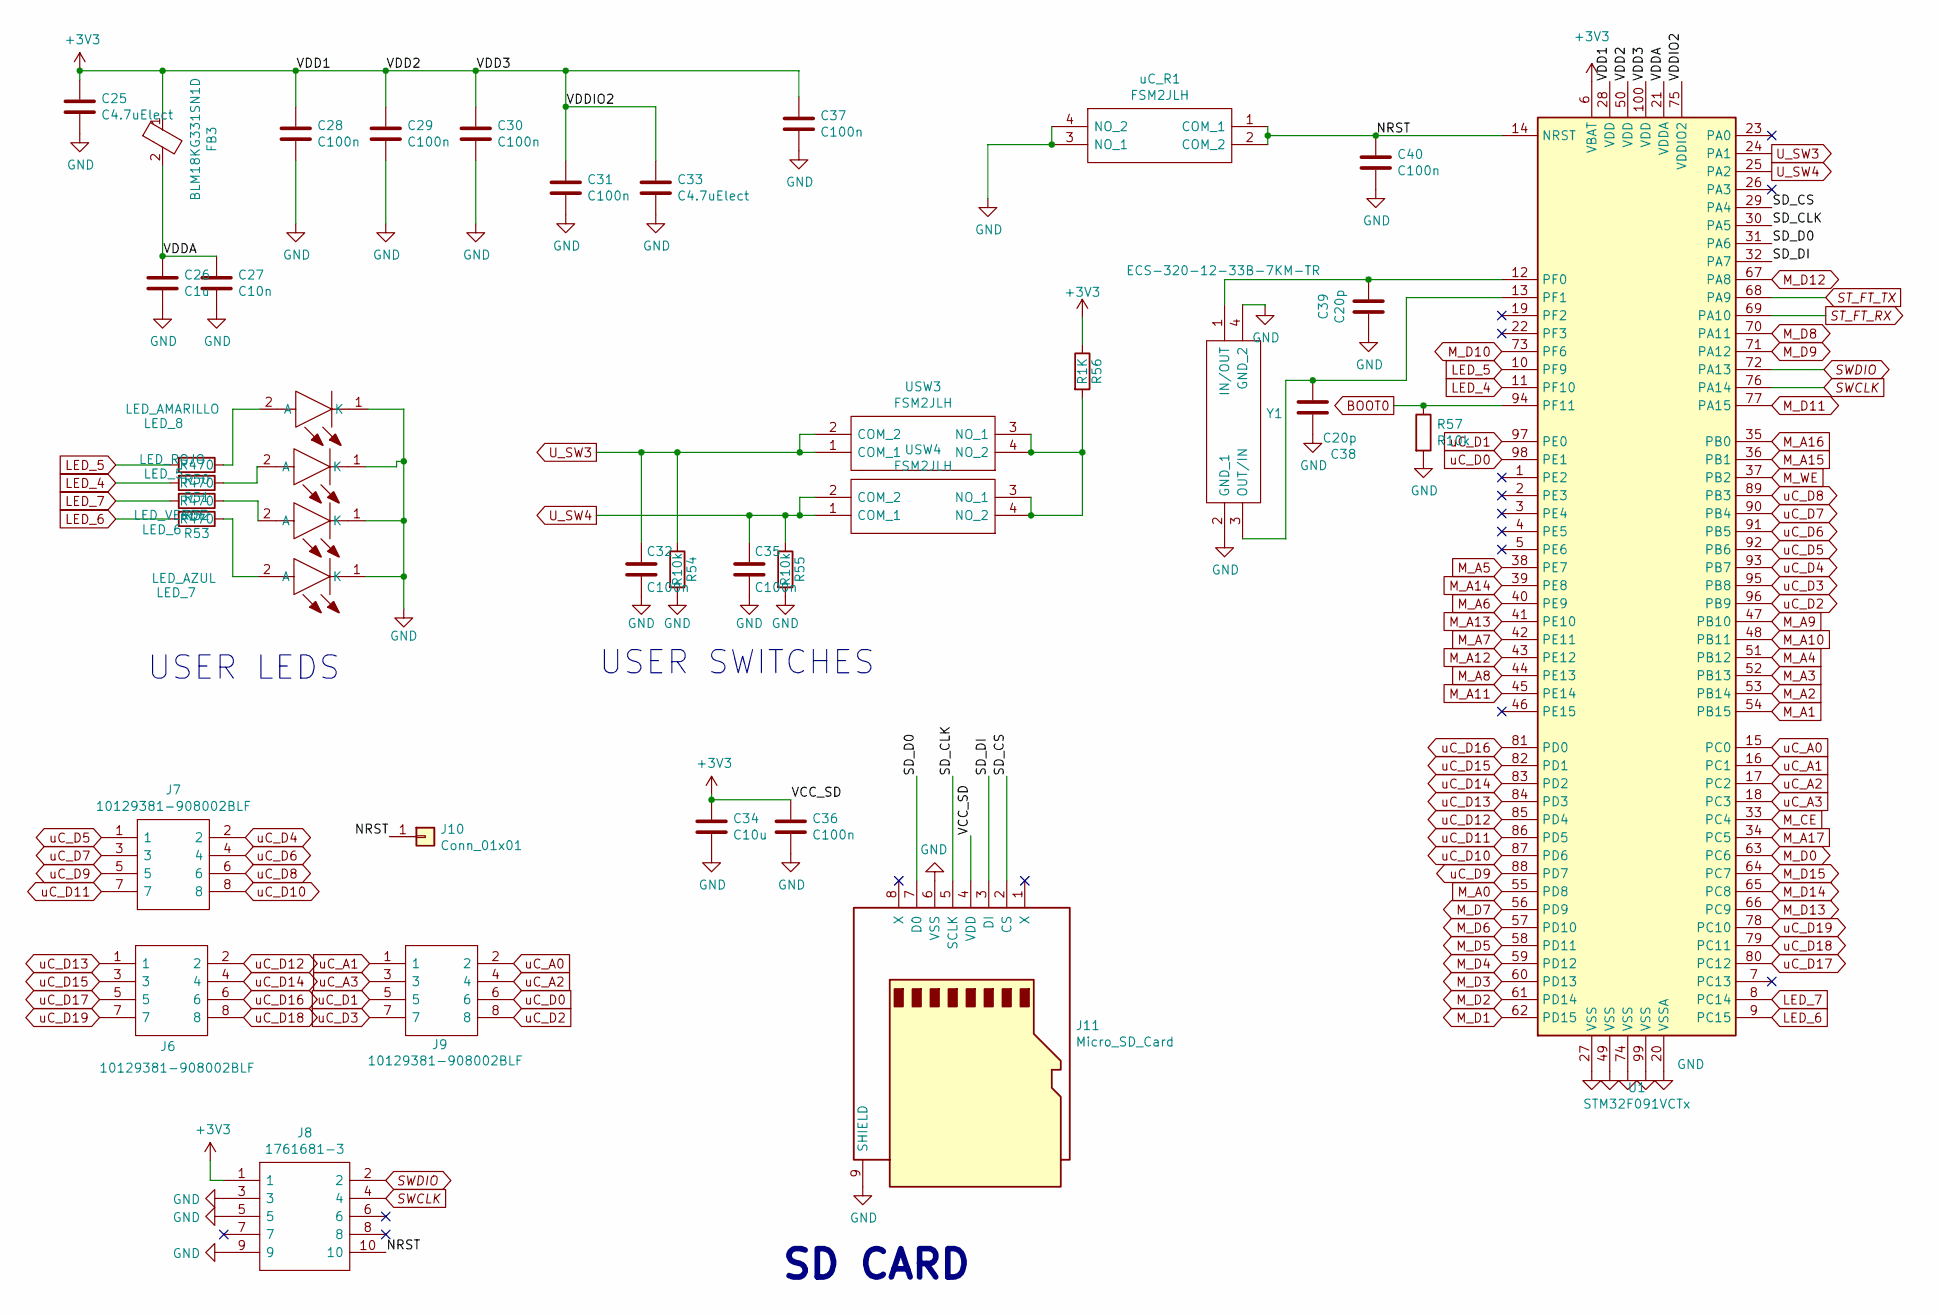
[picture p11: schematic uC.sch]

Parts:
C25, C33: C4.7uElect; C_Elec_5x5.4
C26: C1u; C_1206_3216Metric
C27: C10n; C_1206_3216Metric
C28, C29, C30, C31, C32, C35, C36, C37, C40: C100n; C_0402_1005Metric
C34: C10u; C_0603_1608Metric
C38, C39: C20p; C_0603_1608Metric
FB3: BLM18KG331SN1D; BEADC1608X95N; Manufacturer_Part_Number BLM18KG331SN1D
J6, J7, J9: 10129381-908002BLF; HDRV8W67P254_2X4_1016X483X858P; Mouser Part Number 649-1012938190802BLF
J8: 1761681-3; SHDR10W67P254_2X5_2032X916X922P; Mouser Part Number 571-1761681-3
J10: Conn_01x01; PinHeader_1x01_P2.54mm_Vertical
J11: Micro_SD_Card; microSD_HC_Molex_104031-0811
LED_5: LED_ROJO; LED_0603_1608Metric
LED_6: LED_VERDE; LED_0603_1608Metric
LED_7: LED_AZUL; LED_0603_1608Metric
LED_8: LED_AMARILLO; LED_0603_1608Metric
R50, R51, R52, R53: R470; R_0402_1005Metric
R54, R55, R57: R10k; R_0402_1005Metric
R56: R1K; R_0402_1005Metric
U1: STM32F091VCTx; LQFP-100_14x14mm_P0.5mm
USW3, USW4: FSM2JLH; Mouser Part Number 506-FSM2JLH
Y1: ECS-320-12-33B-7KM-TR; ECS3201233B7KMTR; Mouser Part Number 520-320-12-33B-7KM-T
uC_R1: FSM2JLH; Mouser Part Number 506-FSM2JLH

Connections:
+3V3: C25.1, C28.1, C29.1, C30.1, C31.1, C33.1, C34.1, C36.1, C37.1, FB3.1, J8.1, J11.4 (VDD), R56.1, U1.6 (VBAT), U1.28 (VDD), U1.50 (VDD), U1.75 (VDDIO2), U1.100 (VDD); also elsewhere on the board
/uC/NRST: C40.1, J8.10, J10.1, U1.14 (NRST), uC_R1.1 (COM_1), uC_R1.2 (COM_2)
/uC/SD_CLK: J11.5 (SCLK), U1.30 (PA5)
/uC/SD_CS: J11.2 (CS), U1.29 (PA4)
/uC/SD_D0: J11.7 (D0), U1.31 (PA6)
/uC/SD_DI: J11.3 (DI), U1.32 (PA7)
/uC/VDDA: C26.1, C27.1, FB3.2, U1.21 (VDDA)
BOOT0: R57.1, U1.94 (PF11); also elsewhere on the board
GND: C25.2, C26.2, C27.2, C28.2, C29.2, C30.2, C31.2, C32.2, C33.2, C34.2, C35.2, C36.2, C37.2, C38.1, C39.2, C40.2, J8.3, J8.5, J8.9, J11.6 (VSS), J11.9 (SHIELD), LED_5.1 (K), LED_6.1 (K), LED_7.1 (K), LED_8.1 (K), R54.2, R55.2, R57.2, U1.20 (VSSA), U1.27 (VSS), U1.49 (VSS), U1.74 (VSS), U1.99 (VSS), Y1.2 (GND_1), Y1.4 (GND_2), uC_R1.3 (NO_1), uC_R1.4 (NO_2); also elsewhere on the board
LED_4: R51.2, U1.11 (PF10)
LED_5: R50.2, U1.10 (PF9)
LED_6: R53.2, U1.9 (PC15)
LED_7: R52.2, U1.8 (PC14)
M_A0: U1.55 (PD8); also elsewhere on the board
M_A1: U1.54 (PB15); also elsewhere on the board
M_A2: U1.53 (PB14); also elsewhere on the board
M_A3: U1.52 (PB13); also elsewhere on the board
M_A4: U1.51 (PB12); also elsewhere on the board
M_A5: U1.38 (PE7); also elsewhere on the board
M_A6: U1.40 (PE9); also elsewhere on the board
M_A7: U1.42 (PE11); also elsewhere on the board
M_A8: U1.44 (PE13); also elsewhere on the board
M_A9: U1.47 (PB10); also elsewhere on the board
M_A10: U1.48 (PB11); also elsewhere on the board
M_A11: U1.45 (PE14); also elsewhere on the board
M_A12: U1.43 (PE12); also elsewhere on the board
M_A13: U1.41 (PE10); also elsewhere on the board
M_A14: U1.39 (PE8); also elsewhere on the board
M_A15: U1.36 (PB1); also elsewhere on the board
M_A16: U1.35 (PB0); also elsewhere on the board
M_A17: U1.34 (PC5); also elsewhere on the board
M_CE: U1.33 (PC4); also elsewhere on the board
M_D0: U1.63 (PC6); also elsewhere on the board
M_D1: U1.62 (PD15); also elsewhere on the board
M_D2: U1.61 (PD14); also elsewhere on the board
M_D3: U1.60 (PD13); also elsewhere on the board
M_D4: U1.59 (PD12); also elsewhere on the board
M_D5: U1.58 (PD11); also elsewhere on the board
M_D6: U1.57 (PD10); also elsewhere on the board
M_D7: U1.56 (PD9); also elsewhere on the board
M_D8: U1.70 (PA11); also elsewhere on the board
M_D9: U1.71 (PA12); also elsewhere on the board
M_D10: U1.73 (PF6); also elsewhere on the board
M_D11: U1.77 (PA15); also elsewhere on the board
M_D12: U1.67 (PA8); also elsewhere on the board
M_D13: U1.66 (PC9); also elsewhere on the board
M_D14: U1.65 (PC8); also elsewhere on the board
M_D15: U1.64 (PC7); also elsewhere on the board
M_WE: U1.37 (PB2); also elsewhere on the board
unnamed: C38.2, U1.13 (PF1), Y1.3 (OUT/IN)
unnamed: C39.1, U1.12 (PF0), Y1.1 (IN/OUT)
unnamed: LED_5.2 (A), R51.1
unnamed: LED_6.2 (A), R52.1
unnamed: LED_7.2 (A), R53.1
unnamed: LED_8.2 (A), R50.1
unnamed: R56.2, USW3.3 (NO_1), USW3.4 (NO_2), USW4.3 (NO_1), USW4.4 (NO_2)
ST_FT_RX: U1.69 (PA10); also elsewhere on the board
ST_FT_TX: U1.68 (PA9); also elsewhere on the board
SWCLK: J8.4, U1.76 (PA14)
SWDIO: J8.2, U1.72 (PA13)
U_SW3: C32.1, R54.1, U1.24 (PA1), USW3.1 (COM_1), USW3.2 (COM_2)
U_SW4: C35.1, R55.1, U1.25 (PA2), USW4.1 (COM_1), USW4.2 (COM_2)
uC_A0: J9.2, U1.15 (PC0)
uC_A1: J9.1, U1.16 (PC1)
uC_A2: J9.4, U1.17 (PC2)
uC_A3: J9.3, U1.18 (PC3)
uC_D0: J9.6, U1.98 (PE1)
uC_D1: J9.5, U1.97 (PE0)
uC_D2: J9.8, U1.96 (PB9)
uC_D3: J9.7, U1.95 (PB8)
uC_D4: J7.2, U1.93 (PB7)
uC_D5: J7.1, U1.92 (PB6)
uC_D6: J7.4, U1.91 (PB5)
uC_D7: J7.3, U1.90 (PB4)
uC_D8: J7.6, U1.89 (PB3)
uC_D9: J7.5, U1.88 (PD7)
uC_D10: J7.8, U1.87 (PD6)
uC_D11: J7.7, U1.86 (PD5)
uC_D12: J6.2, U1.85 (PD4)
uC_D13: J6.1, U1.84 (PD3)
uC_D14: J6.4, U1.83 (PD2)
uC_D15: J6.3, U1.82 (PD1)
uC_D16: J6.6, U1.81 (PD0)
uC_D17: J6.5, U1.80 (PC12)
uC_D18: J6.8, U1.79 (PC11)
uC_D19: J6.7, U1.78 (PC10)

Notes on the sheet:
USER SWITCHES
USER LEDS
SD CARD

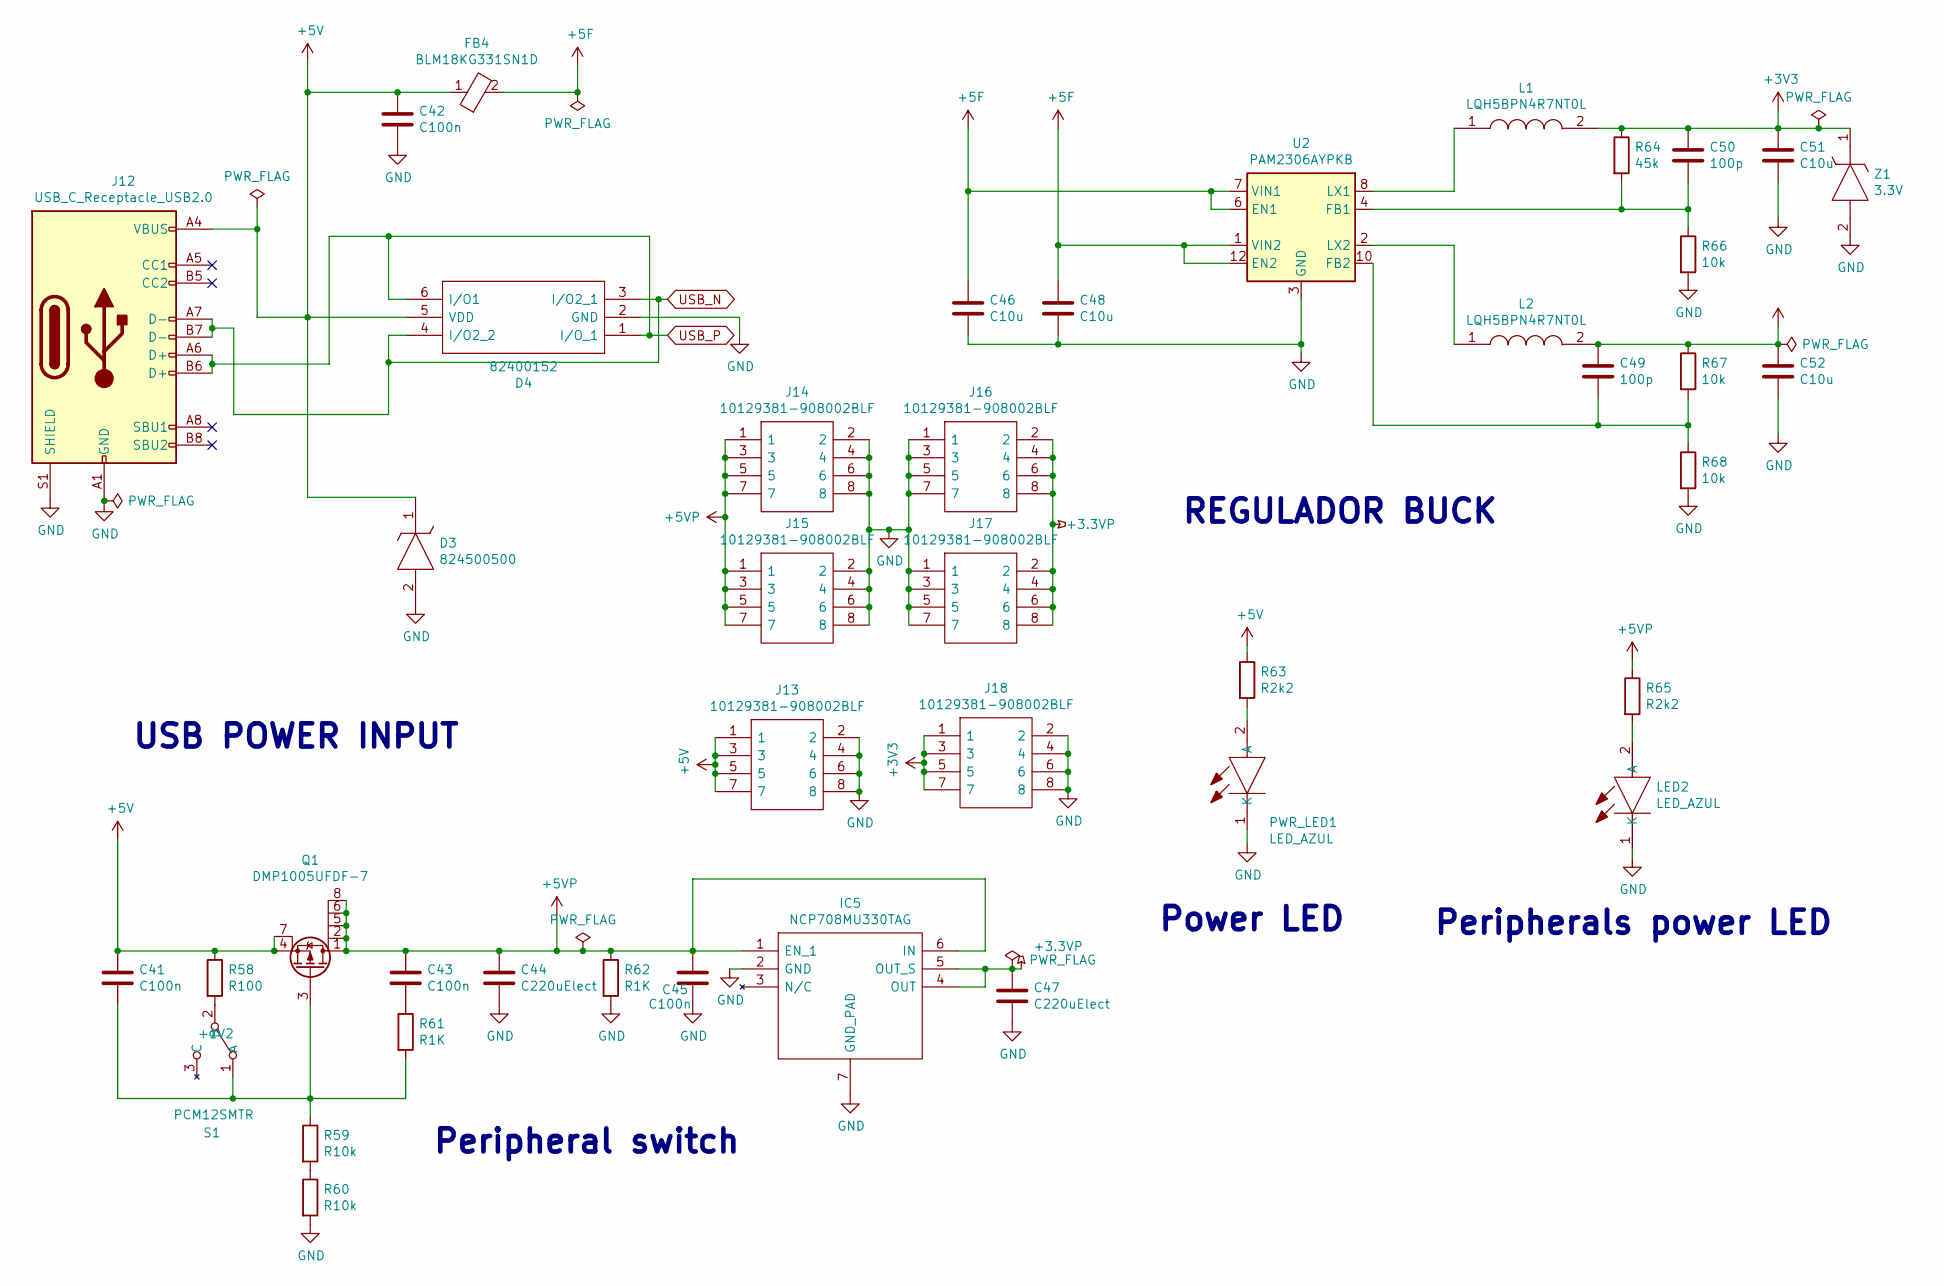
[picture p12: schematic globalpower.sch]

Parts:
C41, C43, C45: C100n; C_0603_1608Metric
C42: C100n; C_0402_1005Metric
C44, C47: C220uElect; CP_Elec_8x10
C46, C48, C51, C52: C10u; C_0603_1608Metric
C49, C50: 100p; C_0603_1608Metric
D3: 824500500; DIOM5127X250N; Mouser Part Number 710-824500500
D4: 82400152; SOTFL50P160X60-6N; Manufacturer_Part_Number 82400152
FB4: BLM18KG331SN1D; BEADC1608X95N; Manufacturer_Part_Number BLM18KG331SN1D
IC5: NCP708MU330TAG; SON95P300X300X55-7N; Mouser Part Number 863-NCP708MU330TAG
J12: USB_C_Receptacle_USB2.0; USB_C_Receptacle_Amphenol_12401610E4-2A
J13, J14, J15, J16, J17, J18: 10129381-908002BLF; HDRV8W67P254_2X4_1016X483X858P; Mouser Part Number 649-1012938190802BLF
L1, L2: LQH5BPN4R7NT0L; LQH5BPB100MT0L; Manufacturer_Part_Number LQH5BPN4R7NT0L
LED2: LED_AZUL; LED_0603_1608Metric
PWR_LED1: LED_AZUL; D_0402_1005Metric
Q1: DMP1005UFDF-7; DFN-6-2EP-2.05-2.05
R58: R100; R_0402_1005Metric
R59, R60: R10k; R_0402_1005Metric
R61, R62: R1K; R_0402_1005Metric
R63, R65: R2k2; R_0603_1608Metric
R64: 45k; R_0603_1608Metric
R66, R67, R68: 10k; R_0402_1005Metric
S1: PCM12SMTR; PCM12SMTR_1; Manufacturer_Part_Number PCM12SMTR
U2: PAM2306AYPKB; WDFN-12-1EP_3x3mm_P0.45mm_EP1.7x2.5mm
Z1: 3.3V; DIOM5436X247N; Manufacturer_Part_Number 1SMB5913BT3G

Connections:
+1V2: C49.1, C52.1, L2.2, R67.1; also elsewhere on the board
+3.3VP: C47.1, IC5.4 (OUT), IC5.5 (OUT_S), J16.2, J16.4, J16.6, J16.8, J17.2, J17.4, J17.6, J17.8
+3V3: C50.1, C51.1, J18.1, J18.3, J18.5, J18.7, L1.2, R64.1, Z1.1; also elsewhere on the board
+5F: C46.1, C48.1, FB4.2, U2.1 (VIN2), U2.6 (EN1), U2.7 (VIN1), U2.12 (EN2)
+5V: C41.1, C42.1, D3.1, D4.5 (VDD), FB4.1, J12.A4 (VBUS), J12.A9 (VBUS), J12.B4 (VBUS), J12.B9 (VBUS), J13.1, J13.3, J13.5, J13.7, Q1.4 (S), Q1.7 (S), R58.1, R63.1; also elsewhere on the board
+5VP: C43.1, C44.1, C45.1, IC5.1 (EN_1), IC5.6 (IN), J14.1, J14.3, J14.5, J14.7, J15.1, J15.3, J15.5, J15.7, Q1.1 (D), Q1.2 (D), Q1.5 (D), Q1.6 (D), Q1.8 (D), R62.1, R65.1
GND: C42.2, C44.2, C45.2, C46.2, C47.2, C48.2, C51.2, C52.2, D3.2, D4.2 (GND), IC5.2 (GND), IC5.7 (GND_PAD), J12.A1 (GND), J12.A12 (GND), J12.B1 (GND), J12.B12 (GND), J12.S1 (SHIELD), J13.2, J13.4, J13.6, J13.8, J14.2, J14.4, J14.6, J14.8, J15.2, J15.4, J15.6, J15.8, J16.1, J16.3, J16.5, J16.7, J17.1, J17.3, J17.5, J17.7, J18.2, J18.4, J18.6, J18.8, LED2.1 (K), PWR_LED1.1 (K), R60.2, R62.2, R66.2, R68.2, U2.3 (GND), U2.9 (GND), U2.13 (GND), Z1.2; also elsewhere on the board
unnamed: C41.2, Q1.3 (G), R59.1, R61.2, S1.1 (A)
unnamed: C43.2, R61.1
unnamed: C49.2, R67.2, R68.1, U2.10 (FB2)
unnamed: C50.2, R64.2, R66.1, U2.4 (FB1)
unnamed: L1.1, U2.8 (LX1)
unnamed: L2.1, U2.2 (LX2)
unnamed: LED2.2 (A), R65.2
unnamed: PWR_LED1.2 (A), R63.2
unnamed: R58.2, S1.2 (B)
unnamed: R59.2, R60.1
USB_N: D4.3 (I/O2_1), D4.4 (I/O2_2), J12.A7 (D-), J12.B7 (D-); also elsewhere on the board
USB_P: D4.1 (I/O_1), D4.6 (I/O1), J12.A6 (D+), J12.B6 (D+); also elsewhere on the board

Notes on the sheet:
USB POWER INPUT
REGULADOR BUCK
Peripheral switch
Peripherals power LED
Power LED

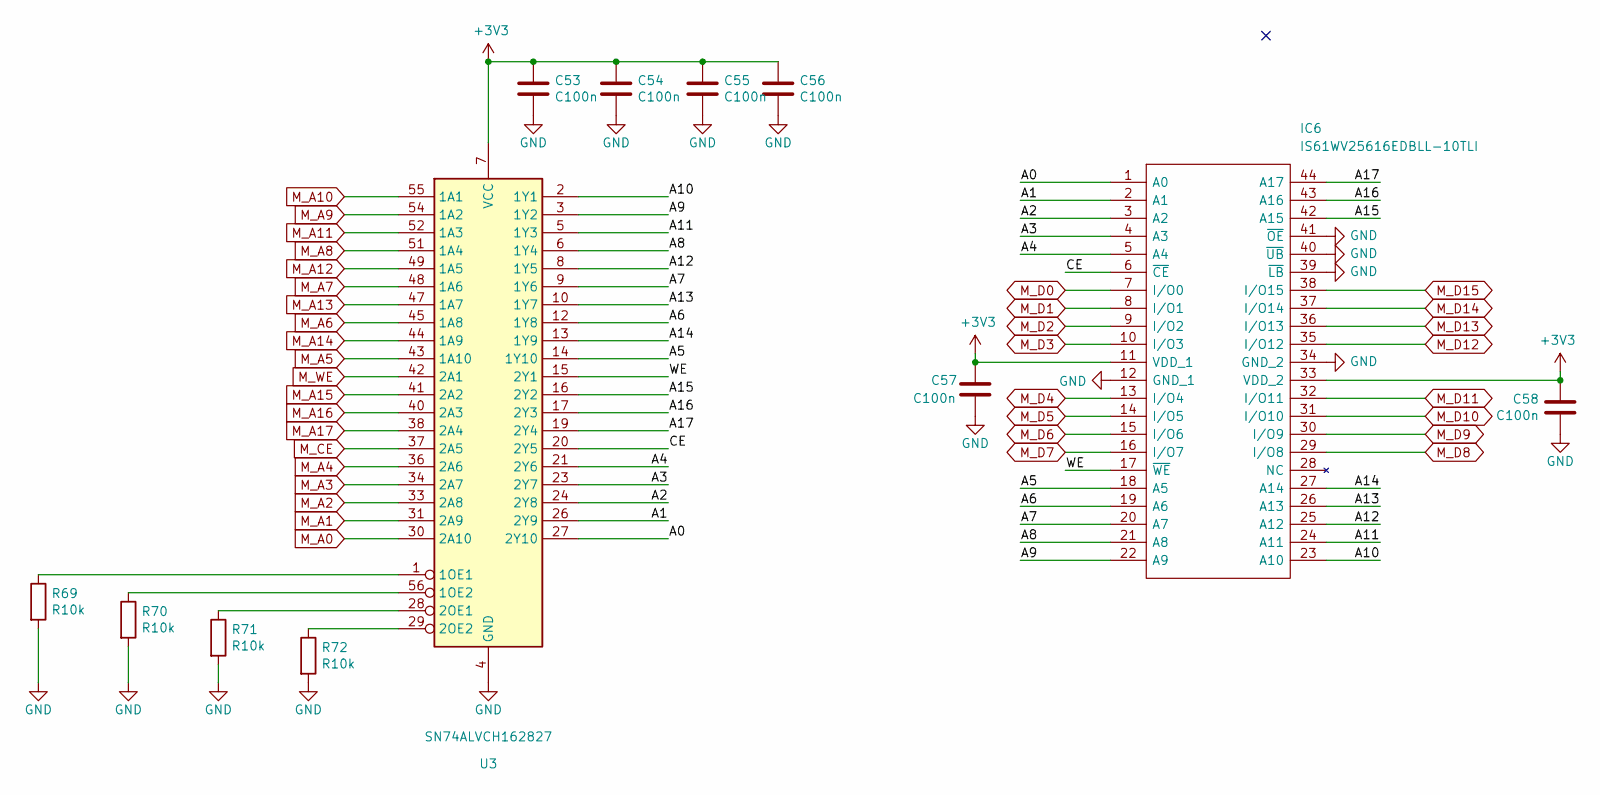
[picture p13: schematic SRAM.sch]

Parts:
C53, C54, C55, C56, C57, C58: C100n; C_0402_1005Metric
IC6: IS61WV25616EDBLL-10TLI; SOP80P1176X120-44N; Mouser Part Number 870-61WV25616EDBLL10
R69, R70, R71, R72: R10k; R_0402_1005Metric
U3: SN74ALVCH162827; TSSOP-56_6.1x14mm_P0.5mm

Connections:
+3V3: C53.1, C54.1, C55.1, C56.1, C57.1, C58.1, IC6.11 (VDD_1), IC6.33 (VDD_2), U3.7 (VCC), U3.22 (VCC), U3.35 (VCC), U3.50 (VCC); also elsewhere on the board
/SRAM/A0: IC6.1 (A0), U3.27 (2Y10)
/SRAM/A1: IC6.2 (A1), U3.26 (2Y9)
/SRAM/A2: IC6.3 (A2), U3.24 (2Y8)
/SRAM/A3: IC6.4 (A3), U3.23 (2Y7)
/SRAM/A4: IC6.5 (A4), U3.21 (2Y6)
/SRAM/A5: IC6.18 (A5), U3.14 (1Y10)
/SRAM/A6: IC6.19 (A6), U3.12 (1Y8)
/SRAM/A7: IC6.20 (A7), U3.9 (1Y6)
/SRAM/A8: IC6.21 (A8), U3.6 (1Y4)
/SRAM/A9: IC6.22 (A9), U3.3 (1Y2)
/SRAM/A10: IC6.23 (A10), U3.2 (1Y1)
/SRAM/A11: IC6.24 (A11), U3.5 (1Y3)
/SRAM/A12: IC6.25 (A12), U3.8 (1Y5)
/SRAM/A13: IC6.26 (A13), U3.10 (1Y7)
/SRAM/A14: IC6.27 (A14), U3.13 (1Y9)
/SRAM/A15: IC6.42 (A15), U3.16 (2Y2)
/SRAM/A16: IC6.43 (A16), U3.17 (2Y3)
/SRAM/A17: IC6.44 (A17), U3.19 (2Y4)
/SRAM/CE: IC6.6 (~CE), U3.20 (2Y5)
/SRAM/WE: IC6.17 (~WE), U3.15 (2Y1)
GND: C53.2, C54.2, C55.2, C56.2, C57.2, C58.2, IC6.12 (GND_1), IC6.34 (GND_2), IC6.39 (~LB), IC6.40 (~UB), IC6.41 (~OE), R69.2, R70.2, R71.2, R72.2, U3.4 (GND), U3.11 (GND), U3.18 (GND), U3.25 (GND), U3.32 (GND), U3.39 (GND), U3.46 (GND), U3.53 (GND); also elsewhere on the board
M_A0: U3.30 (2A10); also elsewhere on the board
M_A1: U3.31 (2A9); also elsewhere on the board
M_A2: U3.33 (2A8); also elsewhere on the board
M_A3: U3.34 (2A7); also elsewhere on the board
M_A4: U3.36 (2A6); also elsewhere on the board
M_A5: U3.43 (1A10); also elsewhere on the board
M_A6: U3.45 (1A8); also elsewhere on the board
M_A7: U3.48 (1A6); also elsewhere on the board
M_A8: U3.51 (1A4); also elsewhere on the board
M_A9: U3.54 (1A2); also elsewhere on the board
M_A10: U3.55 (1A1); also elsewhere on the board
M_A11: U3.52 (1A3); also elsewhere on the board
M_A12: U3.49 (1A5); also elsewhere on the board
M_A13: U3.47 (1A7); also elsewhere on the board
M_A14: U3.44 (1A9); also elsewhere on the board
M_A15: U3.41 (2A2); also elsewhere on the board
M_A16: U3.40 (2A3); also elsewhere on the board
M_A17: U3.38 (2A4); also elsewhere on the board
M_CE: U3.37 (2A5); also elsewhere on the board
M_D0: IC6.7 (I/O0); also elsewhere on the board
M_D1: IC6.8 (I/O1); also elsewhere on the board
M_D2: IC6.9 (I/O2); also elsewhere on the board
M_D3: IC6.10 (I/O3); also elsewhere on the board
M_D4: IC6.13 (I/O4); also elsewhere on the board
M_D5: IC6.14 (I/O5); also elsewhere on the board
M_D6: IC6.15 (I/O6); also elsewhere on the board
M_D7: IC6.16 (I/O7); also elsewhere on the board
M_D8: IC6.29 (I/O8); also elsewhere on the board
M_D9: IC6.30 (I/O9); also elsewhere on the board
M_D10: IC6.31 (I/O10); also elsewhere on the board
M_D11: IC6.32 (I/O11); also elsewhere on the board
M_D12: IC6.35 (I/O12); also elsewhere on the board
M_D13: IC6.36 (I/O13); also elsewhere on the board
M_D14: IC6.37 (I/O14); also elsewhere on the board
M_D15: IC6.38 (I/O15); also elsewhere on the board
M_WE: U3.42 (2A1); also elsewhere on the board
unnamed: R69.1, U3.1 (1OE1)
unnamed: R70.1, U3.56 (1OE2)
unnamed: R71.1, U3.28 (2OE1)
unnamed: R72.1, U3.29 (2OE2)

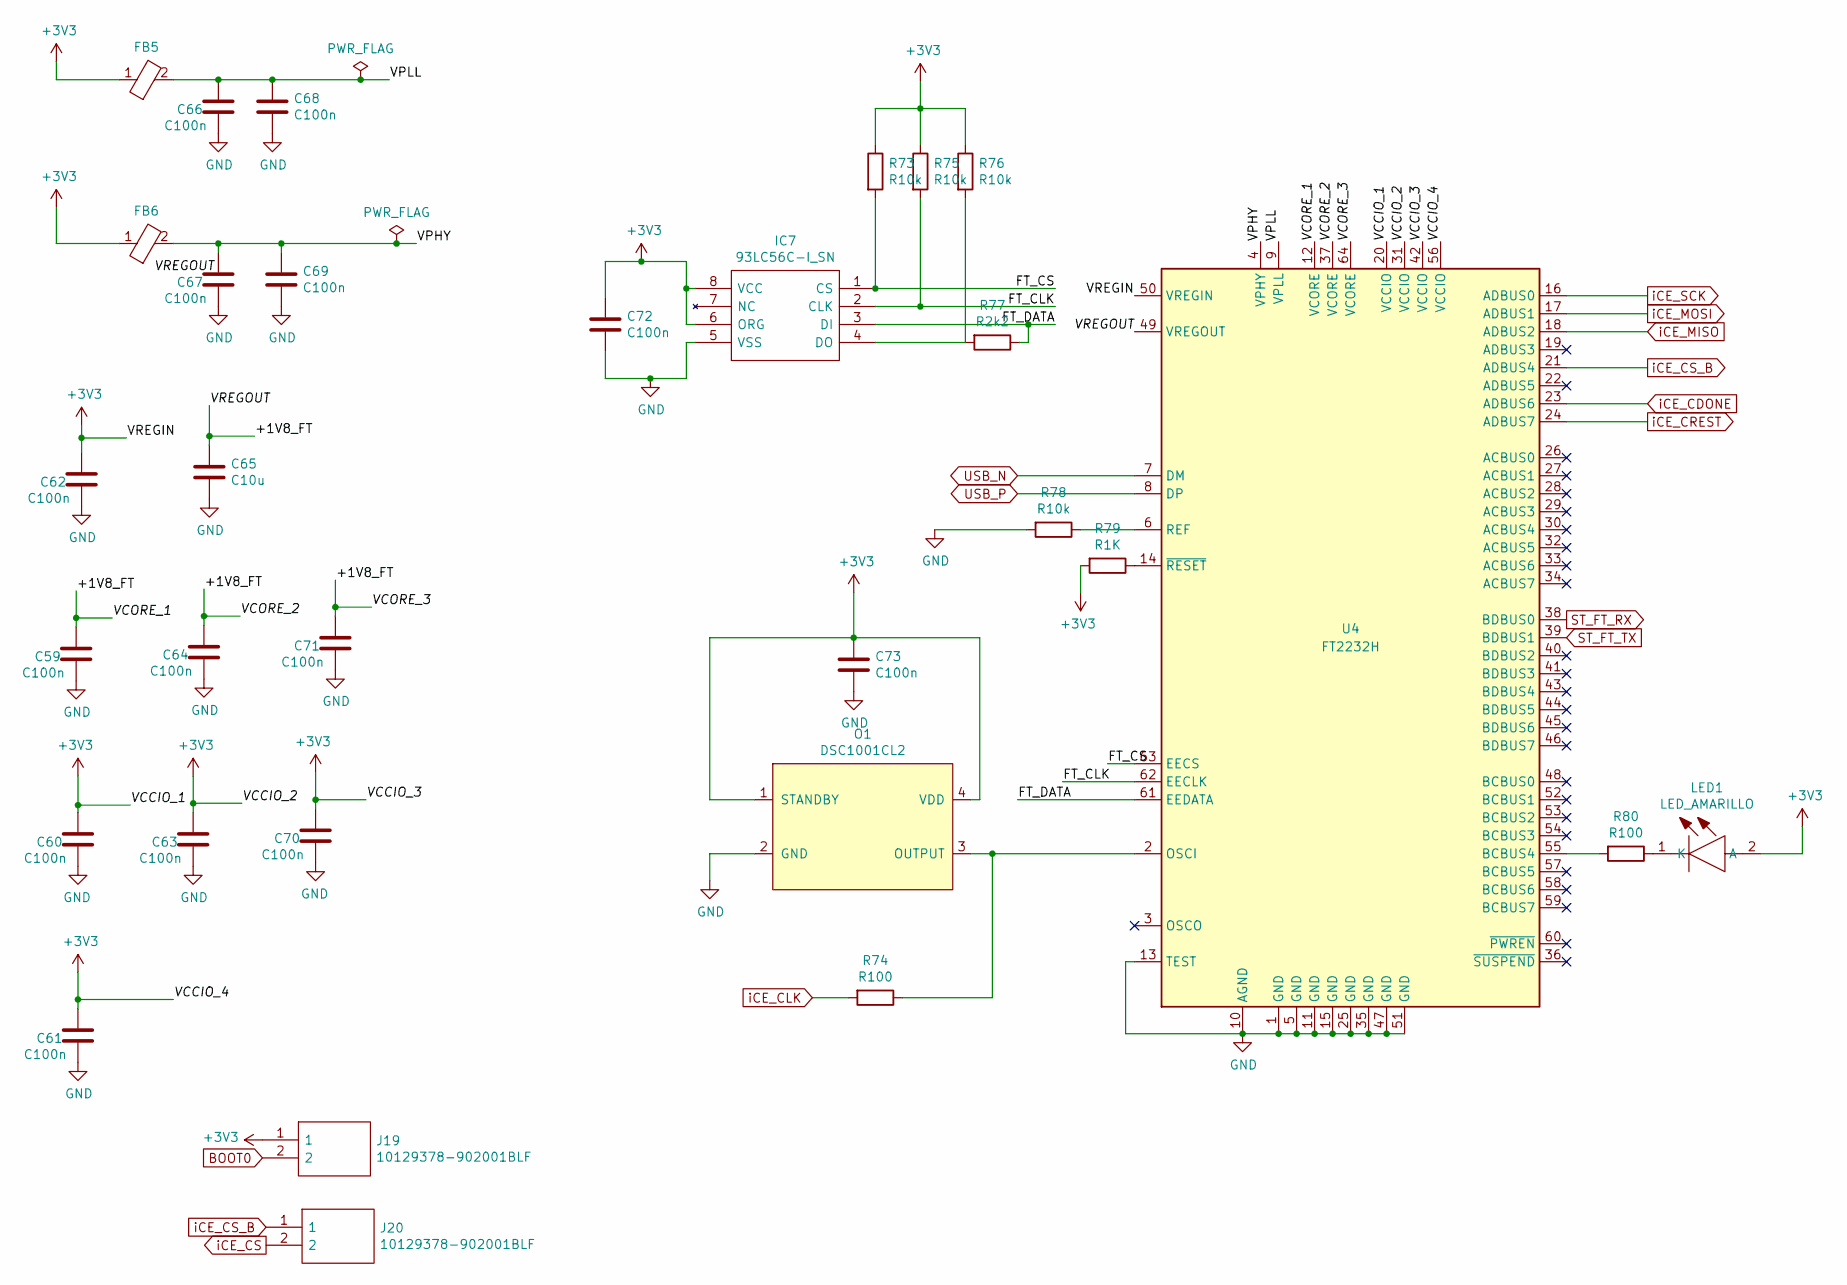
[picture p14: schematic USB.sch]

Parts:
C59, C60, C61, C62, C63, C64, C66, C67, C68, C69, C70, C71, C72, C73: C100n; C_0402_1005Metric
C65: C10u; C_0603_1608Metric
FB5, FB6: BLM18KG331SN1D; BEADC1608X95N; Manufacturer_Part_Number BLM18KG331SN1D
IC7: 93LC56C-I_SN; SOIC127P600X175-8N; Mouser Part Number 579-93LC56C-I/SN
J19, J20: 10129378-902001BLF; HDRV2W67P0X254_1X2_508X241X843P; Mouser Part Number 649-1012937890201BLF
LED1: LED_AMARILLO; LED_0603_1608Metric
O1: DSC1001CL2; DSC1001CI50081920
R73, R75, R76, R78: R10k; R_0402_1005Metric
R74, R80: R100; R_0402_1005Metric
R77: R2k2; R_0402_1005Metric
R79: R1K; R_0402_1005Metric
U4: FT2232H; QFP50P1200X1200X160-64N

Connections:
+3V3: C60.1, C61.1, C62.1, C63.1, C70.1, C72.1, C73.1, FB5.1, FB6.1, IC7.6 (ORG), IC7.8 (VCC), J19.1, LED1.2 (A), O1.1 (STANDBY), O1.4 (VDD), R73.1, R75.1, R76.1, R79.2, U4.20 (VCCIO), U4.31 (VCCIO), U4.42 (VCCIO), U4.50 (VREGIN), U4.56 (VCCIO); also elsewhere on the board
/USB/+1V8_FT: C59.1, C64.1, C65.1, C71.1, U4.12 (VCORE), U4.37 (VCORE), U4.49 (VREGOUT), U4.64 (VCORE)
/USB/FT_CLK: IC7.2 (CLK), R75.2, U4.62 (EECLK)
/USB/FT_CS: IC7.1 (CS), R73.2, U4.63 (EECS)
/USB/FT_DATA: IC7.3 (DI), R77.1, U4.61 (EEDATA)
/USB/VPHY: C67.1, C69.1, FB6.2, U4.4 (VPHY)
/USB/VPLL: C66.1, C68.1, FB5.2, U4.9 (VPLL)
BOOT0: J19.2; also elsewhere on the board
GND: C59.2, C60.2, C61.2, C62.2, C63.2, C64.2, C65.2, C66.2, C67.2, C68.2, C69.2, C70.2, C71.2, C72.2, C73.2, IC7.5 (VSS), O1.2 (GND), R78.2, U4.1 (GND), U4.5 (GND), U4.10 (AGND), U4.11 (GND), U4.13 (TEST), U4.15 (GND), U4.25 (GND), U4.35 (GND), U4.47 (GND), U4.51 (GND); also elsewhere on the board
unnamed: IC7.4 (DO), R76.2, R77.2
unnamed: LED1.1 (K), R80.1
unnamed: O1.3 (OUTPUT), R74.1, U4.2 (OSCI)
unnamed: R78.1, U4.6 (REF)
unnamed: R79.1, U4.14 (~RESET)
unnamed: R80.2, U4.55 (BCBUS4)
ST_FT_RX: U4.38 (BDBUS0); also elsewhere on the board
ST_FT_TX: U4.39 (BDBUS1); also elsewhere on the board
USB_N: U4.7 (DM); also elsewhere on the board
USB_P: U4.8 (DP); also elsewhere on the board
iCE_CDONE: U4.23 (ADBUS6); also elsewhere on the board
iCE_CLK: R74.2; also elsewhere on the board
iCE_CREST: U4.24 (ADBUS7); also elsewhere on the board
iCE_CS: J20.2; also elsewhere on the board
iCE_CS_B: J20.1, U4.21 (ADBUS4)
iCE_MISO: U4.18 (ADBUS2); also elsewhere on the board
iCE_MOSI: U4.17 (ADBUS1); also elsewhere on the board
iCE_SCK: U4.16 (ADBUS0); also elsewhere on the board

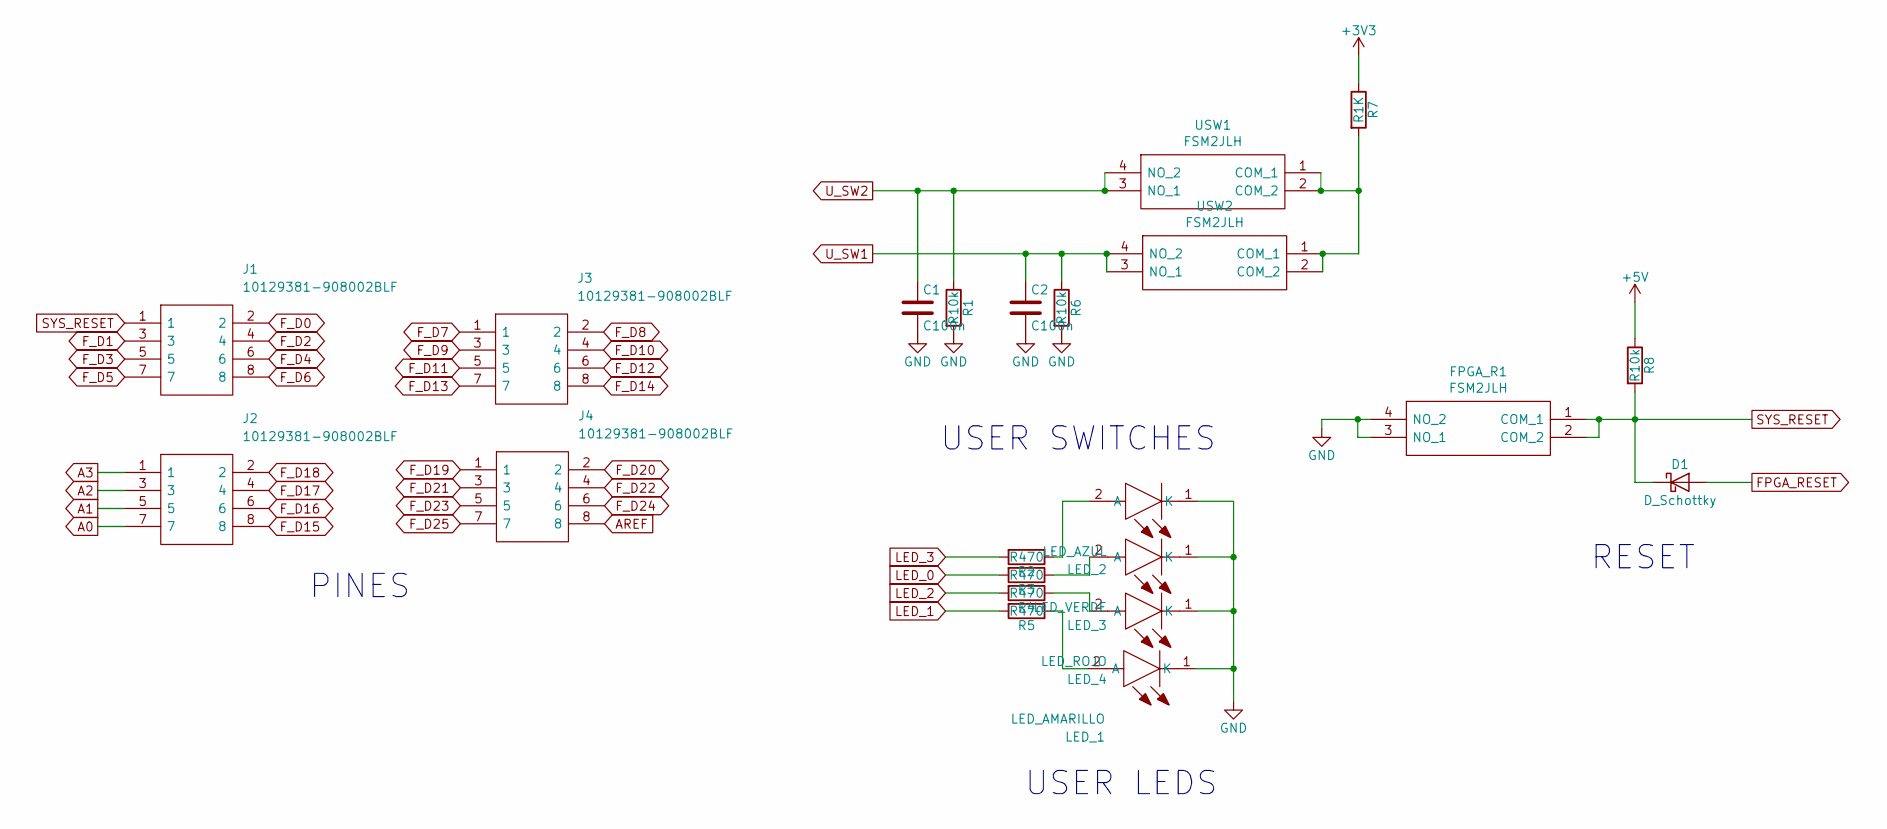
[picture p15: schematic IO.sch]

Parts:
C1, C2: C100n; C_0402_1005Metric
D1: D_Schottky; D_SOD-523
FPGA_R1: FSM2JLH; Mouser Part Number 506-FSM2JLH
J1, J2, J3, J4: 10129381-908002BLF; HDRV8W67P254_2X4_1016X483X858P; Mouser Part Number 649-1012938190802BLF
LED_1: LED_AMARILLO; LED_0603_1608Metric
LED_2: LED_AZUL; LED_0603_1608Metric
LED_3: LED_VERDE; LED_0603_1608Metric
LED_4: LED_ROJO; LED_0603_1608Metric
R1, R6, R8: R10k; R_0402_1005Metric
R2, R3, R4, R5: R470; R_0402_1005Metric
R7: R1K; R_0402_1005Metric
USW1, USW2: FSM2JLH; Mouser Part Number 506-FSM2JLH

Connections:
+3V3: R7.1; also elsewhere on the board
+5V: R8.1; also elsewhere on the board
A0: J2.7; also elsewhere on the board
A1: J2.5; also elsewhere on the board
A2: J2.3; also elsewhere on the board
A3: J2.1; also elsewhere on the board
AREF: J4.8; also elsewhere on the board
FPGA_RESET: D1.2 (A); also elsewhere on the board
F_D0: J1.2; also elsewhere on the board
F_D1: J1.3; also elsewhere on the board
F_D2: J1.4; also elsewhere on the board
F_D3: J1.5; also elsewhere on the board
F_D4: J1.6; also elsewhere on the board
F_D5: J1.7; also elsewhere on the board
F_D6: J1.8; also elsewhere on the board
F_D7: J3.1; also elsewhere on the board
F_D8: J3.2; also elsewhere on the board
F_D9: J3.3; also elsewhere on the board
F_D10: J3.4; also elsewhere on the board
F_D11: J3.5; also elsewhere on the board
F_D12: J3.6; also elsewhere on the board
F_D13: J3.7; also elsewhere on the board
F_D14: J3.8; also elsewhere on the board
F_D15: J2.8; also elsewhere on the board
F_D16: J2.6; also elsewhere on the board
F_D17: J2.4; also elsewhere on the board
F_D18: J2.2; also elsewhere on the board
F_D19: J4.1; also elsewhere on the board
F_D20: J4.2; also elsewhere on the board
F_D21: J4.3; also elsewhere on the board
F_D22: J4.4; also elsewhere on the board
F_D23: J4.5; also elsewhere on the board
F_D24: J4.6; also elsewhere on the board
F_D25: J4.7; also elsewhere on the board
GND: C1.2, C2.2, FPGA_R1.3 (NO_1), FPGA_R1.4 (NO_2), LED_1.1 (K), LED_2.1 (K), LED_3.1 (K), LED_4.1 (K), R1.2, R6.2; also elsewhere on the board
LED_0: R3.2; also elsewhere on the board
LED_1: R5.2; also elsewhere on the board
LED_2: R4.2; also elsewhere on the board
LED_3: R2.2; also elsewhere on the board
unnamed: LED_1.2 (A), R5.1
unnamed: LED_2.2 (A), R2.1
unnamed: LED_3.2 (A), R3.1
unnamed: LED_4.2 (A), R4.1
unnamed: R7.2, USW1.1 (COM_1), USW1.2 (COM_2), USW2.1 (COM_1), USW2.2 (COM_2)
SYS_RESET: D1.1 (K), FPGA_R1.1 (COM_1), FPGA_R1.2 (COM_2), J1.1, R8.2
U_SW1: C2.1, R6.1, USW2.3 (NO_1), USW2.4 (NO_2); also elsewhere on the board
U_SW2: C1.1, R1.1, USW1.3 (NO_1), USW1.4 (NO_2); also elsewhere on the board

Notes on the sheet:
USER SWITCHES
USER LEDS
PINES
RESET

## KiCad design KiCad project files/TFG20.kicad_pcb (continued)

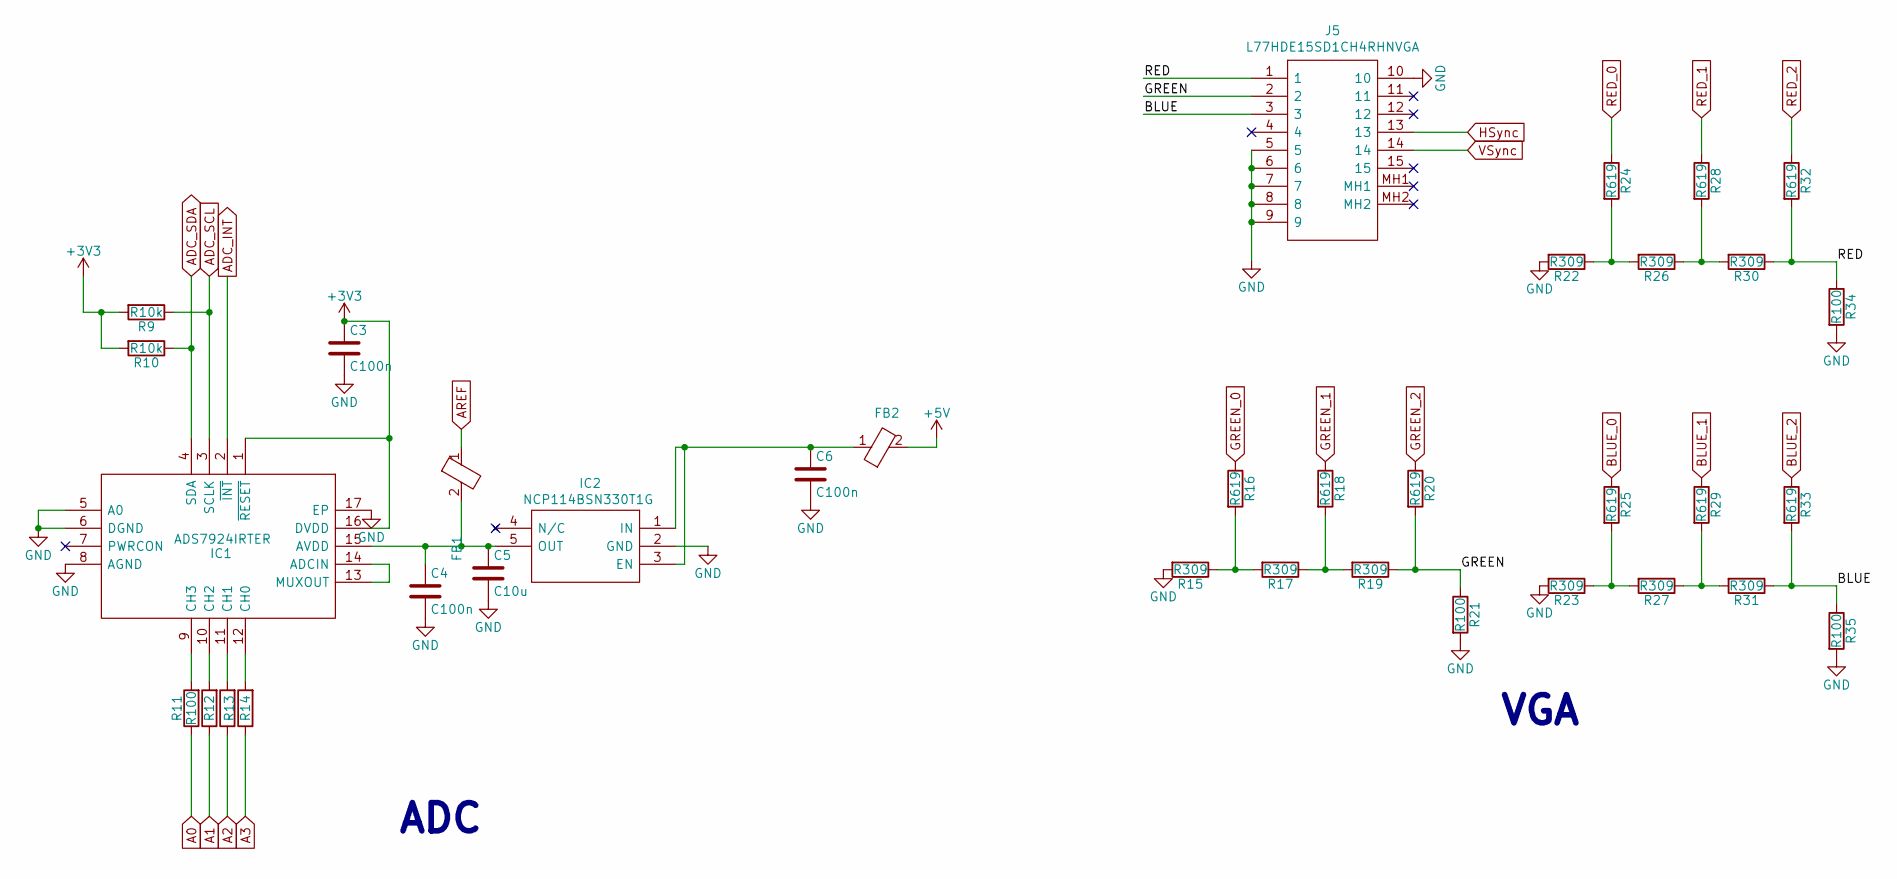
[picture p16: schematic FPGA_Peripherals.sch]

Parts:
C3, C4, C6: C100n; C_0603_1608Metric
C5: C10u; C_0603_1608Metric
FB1, FB2: BLM18KG331SN1D; BEADC1608X95N; Manufacturer_Part_Number BLM18KG331SN1D
IC1: ADS7924IRTER; QFN50P300X300X80-17N-D; Mouser Part Number 595-ADS7924IRTER
IC2: NCP114BSN330T1G; SOT95P275X110-5N; Manufacturer_Part_Number NCP114BSN330T1G
J5: L77HDE15SD1CH4RHNVGA; Mouser Part Number 523-7HDE15SDH4RHNVGA
R9, R10: R10k; R_0402_1005Metric
R11, R12, R13, R14, R21, R34, R35: R100; R_0402_1005Metric
R15, R17, R19, R22, R23, R26, R27, R30, R31: R309; R_0805_2012Metric
R16, R18, R20, R24, R25, R28, R29, R32, R33: R619; R_0402_1005Metric

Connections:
+3V3: C3.1, IC1.1 (~RESET), IC1.16 (DVDD), R9.2, R10.2; also elsewhere on the board
+5V: FB2.2; also elsewhere on the board
/FPGA/FPGA_Peripherals/BLUE: J5.3, R31.1, R33.2, R35.1
/FPGA/FPGA_Peripherals/GREEN: J5.2, R19.1, R20.2, R21.1
/FPGA/FPGA_Peripherals/RED: J5.1, R30.1, R32.2, R34.1
A0: R11.1; also elsewhere on the board
A1: R12.1; also elsewhere on the board
A2: R13.1; also elsewhere on the board
A3: R14.1; also elsewhere on the board
ADC_INT: IC1.2 (~INT); also elsewhere on the board
ADC_SCL: IC1.3 (SCLK), R9.1; also elsewhere on the board
ADC_SDA: IC1.4 (SDA), R10.1; also elsewhere on the board
AREF: FB1.1; also elsewhere on the board
BLUE_0: R25.1; also elsewhere on the board
BLUE_1: R29.1; also elsewhere on the board
BLUE_2: R33.1; also elsewhere on the board
GND: C3.2, C4.2, C5.2, C6.2, IC1.5 (A0), IC1.6 (DGND), IC1.8 (AGND), IC1.17 (EP), IC2.2 (GND), J5.5, J5.6, J5.7, J5.8, J5.9, J5.10, R15.2, R21.2, R22.2, R23.2, R34.2, R35.2; also elsewhere on the board
GREEN_0: R16.1; also elsewhere on the board
GREEN_1: R18.1; also elsewhere on the board
GREEN_2: R20.1; also elsewhere on the board
HSync: J5.13; also elsewhere on the board
unnamed: C4.1, C5.1, FB1.2, IC1.15 (AVDD), IC2.5 (OUT)
unnamed: C6.1, FB2.1, IC2.1 (IN), IC2.3 (EN)
unnamed: IC1.9 (CH3), R11.2
unnamed: IC1.10 (CH2), R12.2
unnamed: IC1.11 (CH1), R13.2
unnamed: IC1.12 (CH0), R14.2
unnamed: IC1.13 (MUXOUT), IC1.14 (ADCIN)
unnamed: R15.1, R16.2, R17.2
unnamed: R17.1, R18.2, R19.2
unnamed: R22.1, R24.2, R26.2
unnamed: R23.1, R25.2, R27.2
unnamed: R26.1, R28.2, R30.2
unnamed: R27.1, R29.2, R31.2
RED_0: R24.1; also elsewhere on the board
RED_1: R28.1; also elsewhere on the board
RED_2: R32.1; also elsewhere on the board
VSync: J5.14; also elsewhere on the board

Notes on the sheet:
ADC
VGA

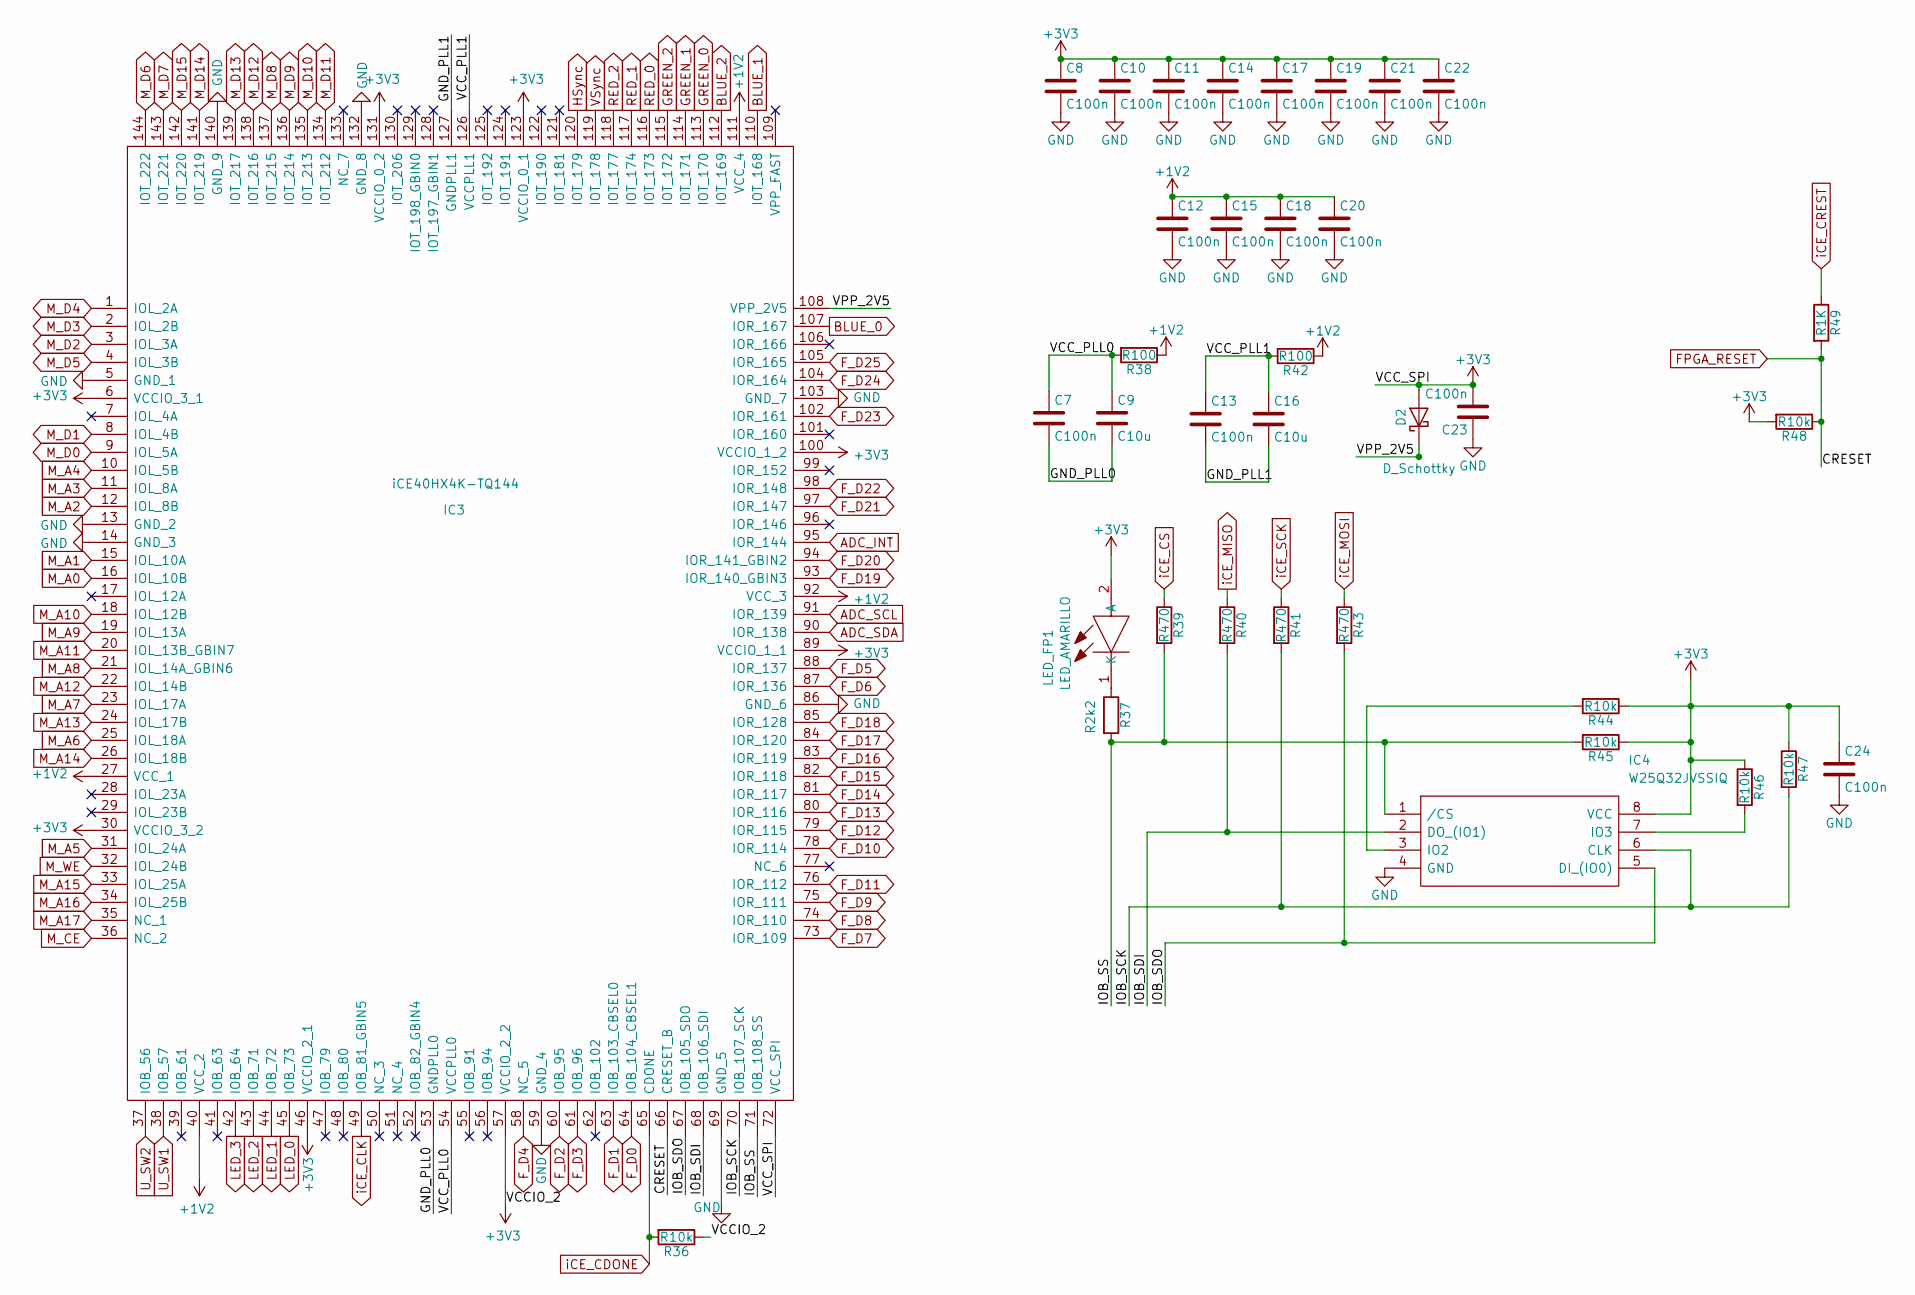
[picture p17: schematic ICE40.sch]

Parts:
C7, C8, C10, C11, C12, C13, C14, C15, C17, C18, C19, C20, C21, C22, C23, C24: C100n; C_0402_1005Metric
C9, C16: C10u; C_0603_1608Metric
D2: D_Schottky; D_SOD-523
IC3: iCE40HX4K-TQ144; QFP50P2200X2200X160-144N; Mouser Part Number 842-ICE40HX4K-TQ144
IC4: W25Q32JVSSIQ; SOIC127P790X216-8N; Manufacturer_Part_Number W25Q32JVSSIQ
LED_FP1: LED_AMARILLO; LED_0603_1608Metric; Manufacturer_Part_Number KP-2012SYC
R36, R44, R45, R46, R47, R48: R10k; R_0402_1005Metric
R37: R2k2; R_0402_1005Metric
R38, R42: R100; R_0402_1005Metric
R39, R40, R41, R43: R470; R_0402_1005Metric
R49: R1K; R_0402_1005Metric

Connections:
+1V2: C12.1, C15.1, C18.1, C20.1, IC3.27 (VCC_1), IC3.40 (VCC_2), IC3.92 (VCC_3), IC3.111 (VCC_4), R38.1, R42.1; also elsewhere on the board
+3V3: C8.1, C10.1, C11.1, C14.1, C17.1, C19.1, C21.1, C22.1, C23.2, C24.1, D2.2 (A), IC3.6 (VCCIO_3_1), IC3.30 (VCCIO_3_2), IC3.46 (VCCIO_2_1), IC3.57 (VCCIO_2_2), IC3.72 (VCC_SPI), IC3.89 (VCCIO_1_1), IC3.100 (VCCIO_1_2), IC3.123 (VCCIO_0_1), IC3.131 (VCCIO_0_2), IC4.8 (VCC), LED_FP1.2 (A), R36.1, R44.1, R45.1, R46.1, R47.1, R48.2; also elsewhere on the board
/FPGA/ICE40/GND_PLL0: C7.2, C9.2, IC3.53 (GNDPLL0)
/FPGA/ICE40/GND_PLL1: C13.2, C16.2, IC3.127 (GNDPLL1)
/FPGA/ICE40/IOB_SCK: IC3.70 (IOB_107_SCK), IC4.6 (CLK), R41.2, R47.2
/FPGA/ICE40/IOB_SDI: IC3.68 (IOB_106_SDI), IC4.2 (DO_(IO1)), R40.2
/FPGA/ICE40/IOB_SDO: IC3.67 (IOB_105_SDO), IC4.5 (DI_(IO0)), R43.2
/FPGA/ICE40/IOB_SS: IC3.71 (IOB_108_SS), IC4.1 (/CS), R37.2, R39.2, R45.2
/FPGA/ICE40/VCC_PLL0: C7.1, C9.1, IC3.54 (VCCPLL0), R38.2
/FPGA/ICE40/VCC_PLL1: C13.1, C16.1, IC3.126 (VCCPLL1), R42.2
/FPGA/ICE40/VPP_2V5: D2.1 (K), IC3.108 (VPP_2V5)
ADC_INT: IC3.95 (IOR_144); also elsewhere on the board
ADC_SCL: IC3.91 (IOR_139); also elsewhere on the board
ADC_SDA: IC3.90 (IOR_138); also elsewhere on the board
BLUE_0: IC3.107 (IOR_167); also elsewhere on the board
BLUE_1: IC3.110 (IOT_168); also elsewhere on the board
BLUE_2: IC3.112 (IOT_169); also elsewhere on the board
FPGA_RESET: IC3.66 (CRESET_B), R48.1, R49.2; also elsewhere on the board
F_D0: IC3.64 (IOB_104_CBSEL1); also elsewhere on the board
F_D1: IC3.63 (IOB_103_CBSEL0); also elsewhere on the board
F_D2: IC3.60 (IOB_95); also elsewhere on the board
F_D3: IC3.61 (IOB_96); also elsewhere on the board
F_D4: IC3.58 (NC_5); also elsewhere on the board
F_D5: IC3.88 (IOR_137); also elsewhere on the board
F_D6: IC3.87 (IOR_136); also elsewhere on the board
F_D7: IC3.73 (IOR_109); also elsewhere on the board
F_D8: IC3.74 (IOR_110); also elsewhere on the board
F_D9: IC3.75 (IOR_111); also elsewhere on the board
F_D10: IC3.78 (IOR_114); also elsewhere on the board
F_D11: IC3.76 (IOR_112); also elsewhere on the board
F_D12: IC3.79 (IOR_115); also elsewhere on the board
F_D13: IC3.80 (IOR_116); also elsewhere on the board
F_D14: IC3.81 (IOR_117); also elsewhere on the board
F_D15: IC3.82 (IOR_118); also elsewhere on the board
F_D16: IC3.83 (IOR_119); also elsewhere on the board
F_D17: IC3.84 (IOR_120); also elsewhere on the board
F_D18: IC3.85 (IOR_128); also elsewhere on the board
F_D19: IC3.93 (IOR_140_GBIN3); also elsewhere on the board
F_D20: IC3.94 (IOR_141_GBIN2); also elsewhere on the board
F_D21: IC3.97 (IOR_147); also elsewhere on the board
F_D22: IC3.98 (IOR_148); also elsewhere on the board
F_D23: IC3.102 (IOR_161); also elsewhere on the board
F_D24: IC3.104 (IOR_164); also elsewhere on the board
F_D25: IC3.105 (IOR_165); also elsewhere on the board
GND: C8.2, C10.2, C11.2, C12.2, C14.2, C15.2, C17.2, C18.2, C19.2, C20.2, C21.2, C22.2, C23.1, C24.2, IC3.5 (GND_1), IC3.13 (GND_2), IC3.14 (GND_3), IC3.59 (GND_4), IC3.69 (GND_5), IC3.86 (GND_6), IC3.103 (GND_7), IC3.132 (GND_8), IC3.140 (GND_9), IC4.4 (GND); also elsewhere on the board
GREEN_0: IC3.113 (IOT_170); also elsewhere on the board
GREEN_1: IC3.114 (IOT_171); also elsewhere on the board
GREEN_2: IC3.115 (IOT_172); also elsewhere on the board
HSync: IC3.120 (IOT_179); also elsewhere on the board
LED_0: IC3.45 (IOB_73); also elsewhere on the board
LED_1: IC3.44 (IOB_72); also elsewhere on the board
LED_2: IC3.43 (IOB_71); also elsewhere on the board
LED_3: IC3.42 (IOB_64); also elsewhere on the board
M_A0: IC3.16 (IOL_10B); also elsewhere on the board
M_A1: IC3.15 (IOL_10A); also elsewhere on the board
M_A2: IC3.12 (IOL_8B); also elsewhere on the board
M_A3: IC3.11 (IOL_8A); also elsewhere on the board
M_A4: IC3.10 (IOL_5B); also elsewhere on the board
M_A5: IC3.31 (IOL_24A); also elsewhere on the board
M_A6: IC3.25 (IOL_18A); also elsewhere on the board
M_A7: IC3.23 (IOL_17A); also elsewhere on the board
M_A8: IC3.21 (IOL_14A_GBIN6); also elsewhere on the board
M_A9: IC3.19 (IOL_13A); also elsewhere on the board
M_A10: IC3.18 (IOL_12B); also elsewhere on the board
M_A11: IC3.20 (IOL_13B_GBIN7); also elsewhere on the board
M_A12: IC3.22 (IOL_14B); also elsewhere on the board
M_A13: IC3.24 (IOL_17B); also elsewhere on the board
M_A14: IC3.26 (IOL_18B); also elsewhere on the board
M_A15: IC3.33 (IOL_25A); also elsewhere on the board
M_A16: IC3.34 (IOL_25B); also elsewhere on the board
M_A17: IC3.35 (NC_1); also elsewhere on the board
M_CE: IC3.36 (NC_2); also elsewhere on the board
M_D0: IC3.9 (IOL_5A); also elsewhere on the board
M_D1: IC3.8 (IOL_4B); also elsewhere on the board
M_D2: IC3.3 (IOL_3A); also elsewhere on the board
M_D3: IC3.2 (IOL_2B); also elsewhere on the board
M_D4: IC3.1 (IOL_2A); also elsewhere on the board
M_D5: IC3.4 (IOL_3B); also elsewhere on the board
M_D6: IC3.144 (IOT_222); also elsewhere on the board
M_D7: IC3.143 (IOT_221); also elsewhere on the board
M_D8: IC3.137 (IOT_215); also elsewhere on the board
M_D9: IC3.136 (IOT_214); also elsewhere on the board
M_D10: IC3.135 (IOT_213); also elsewhere on the board
M_D11: IC3.134 (IOT_212); also elsewhere on the board
M_D12: IC3.138 (IOT_216); also elsewhere on the board
M_D13: IC3.139 (IOT_217); also elsewhere on the board
M_D14: IC3.141 (IOT_219); also elsewhere on the board
M_D15: IC3.142 (IOT_220); also elsewhere on the board
M_WE: IC3.32 (IOL_24B); also elsewhere on the board
unnamed: IC4.3 (IO2), R44.2
unnamed: IC4.7 (IO3), R46.2
unnamed: LED_FP1.1 (K), R37.1
RED_0: IC3.116 (IOT_173); also elsewhere on the board
RED_1: IC3.117 (IOT_174); also elsewhere on the board
RED_2: IC3.118 (IOT_177); also elsewhere on the board
U_SW1: IC3.38 (IOB_57); also elsewhere on the board
U_SW2: IC3.37 (IOB_56); also elsewhere on the board
VSync: IC3.119 (IOT_178); also elsewhere on the board
iCE_CDONE: IC3.65 (CDONE), R36.2; also elsewhere on the board
iCE_CLK: IC3.49 (IOB_81_GBIN5); also elsewhere on the board
iCE_CREST: R49.1; also elsewhere on the board
iCE_CS: R39.1; also elsewhere on the board
iCE_MISO: R40.1; also elsewhere on the board
iCE_MOSI: R43.1; also elsewhere on the board
iCE_SCK: R41.1; also elsewhere on the board

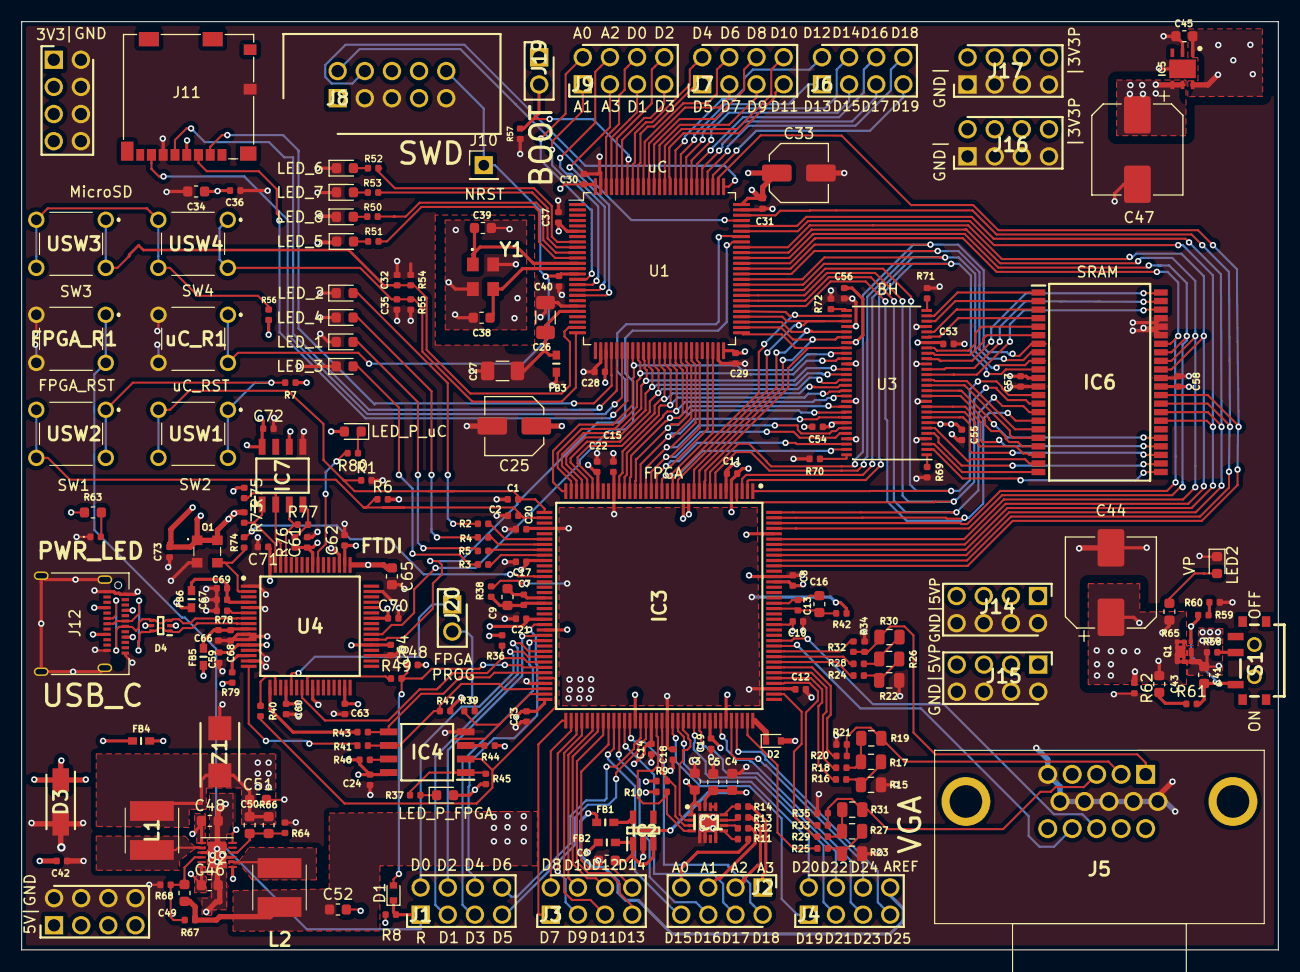
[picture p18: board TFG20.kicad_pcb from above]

Board: 4 copper layers, 117.6 x 86.9 mm, 219 parts (0 on the bottom side), 233 nets.

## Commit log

2020-07-30 Create KiCad files
2020-07-30 Rename ADC.sch to KiCad files/ADC.sch
    [ADC.sch]
